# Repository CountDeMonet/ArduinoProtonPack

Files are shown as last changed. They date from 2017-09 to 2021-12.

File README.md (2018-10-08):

# Arduino Based Ghostbusters Proton Pack
Arduino Code for a Ghostbusters Neutrino Wand and Proton Pack

I'm in the process of building a proton pack for my son and this is the progress I have made so far. I have included the models for 3d printing, all sounds but the ghostbusters theme song, and the arduino code to control all of this. The models for 3d printing are scaled to 83%. The proton pack models are also mirrored for a left handed users pack. Once I have some time I'll post non-mirrored files. 

The models are based off the following things on thingiverse: 
* Main base model for the pack: https://www.thingiverse.com/thing:2479141
* Base model for the proton wand: https://www.thingiverse.com/thing:1128019
* Full scale proton wand the 83% one is based on: https://www.thingiverse.com/thing:2334883
* And a clippard valve with text: https://www.thingiverse.com/thing:2286284

This pack utilizes many off the shelf products for the electronics to make the build as easy as possible. Total cost is around $80 for the parts if sourced from amazon. You can find cheaper on ebay

* 1 arduino nano. You get 3 for $11.86: https://www.amazon.com/gp/product/B0713XK923
* 2 power converters to adjust the 11.1v lipo to 5v. You get 6 for $9.69: https://www.amazon.com/gp/product/B01MQGMOKI
* 1 Adafruit Audio FX Sound Board. It's the most expensive part at $23.80 but is awesome to work with: https://www.amazon.com/gp/product/B00Q3U42DM
* Audio amp $6.01 each: https://www.amazon.com/gp/product/B00PY2YSI4
* small speaker for my 83% scale build. You get 2 for $8.05. https://www.amazon.com/gp/product/B00NQ0LHNA
* 4 neopixel jewels for the cyclotron @ 5.49 each: https://www.amazon.com/gp/product/B0105VMT4S
* 1 neopixel jewels for the end of the wand @ 5.49 each: https://www.amazon.com/gp/product/B0105VMT4S
* two 8 neopixel light stick for the powercell @9.99 each: https://www.amazon.com/Adafruit-NeoPixel-Arduino-Integrated-Drivers/dp/B00IEDH26K
* Individual neopixels for venting, wand lights, and for the cyclotron if doing the spirit version. 100 for $16: https://www.amazon.com/Kuman-WS2812B-Addressable-Arduino-littlergb/dp/B01M5BEO1C
* 4 toggle switches:https://www.amazon.com/gp/product/B00HGAKDIQ
* 1 button:  https://www.amazon.com/gp/product/B01IU898QA
* 11.1v lipo to power the whole thing: https://www.amazon.com/Gens-ace-Battery-2200mAh-Airplane/dp/B00WJN4LG0

I bought the light covers from digikey

https://www.digikey.com/product-detail/en/visual-communications-company-vcc/CLF_280_ATP/CLF_280_ATP-ND/4515437 - light near the clippard
https://www.digikey.com/product-detail/en/visual-communications-company-vcc/SMB_200_RTP/SMB_200_RTP-ND/4515614 - sloblo
https://www.digikey.com/product-detail/en/visual-communications-company-vcc/SML_190_CTP/SML_190_CTP-ND/4515623 - Vent light front
https://www.digikey.com/product-detail/en/visual-communications-company-vcc/CMC_321_YTP/CMC_321_YTP-ND/4515456 - Vent light rear (no led tied to this one)

For the optional bargraph we are using the SparkFun SX1509 expander board and some resitor networks/bargraphs from digikey. If you want to use the bargraph you need to move the code from the test file into the main file and overwrite the stub functions. Since I won't be using it in my son's pack I removed it from the main file 
https://learn.sparkfun.com/tutorials/sx1509-io-expander-breakout-hookup-guide

* https://www.digikey.com/product-detail/en/sparkfun-electronics/BOB-13601/1568-1186-ND/5673772
* https://www.digikey.com/product-detail/en/bourns-inc/4611X-101-331LF/4611X-101-331LF-ND/3787988
* https://www.digikey.com/product-detail/en/bourns-inc/4606X-101-331LF/4606X-1-331LF-ND/1088983
* https://www.digikey.com/product-detail/en/sunled/XGUYX10D/1497-1086-5-ND/4745985
* https://www.digikey.com/product-detail/en/sunled/XGUYX5D/1497-1087-5-ND/4745584

Here's a video of the whole shebang put together

IMAGE ALT TEXT (https://www.youtube.com/watch?v=shoYI2D1AxI "Ghostbusters Arduino Proton Pack Update")

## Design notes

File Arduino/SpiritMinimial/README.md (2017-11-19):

I had a bunch of extra components lying around so I decided I would use them to upgrade the lighting on my Spirit pack. I wanted the standard powercell and cyclotron animations while I walk around. I kept the flashing light in the powercell when firing the wand but removed them on the cyclotron.  The result can be seen here:

IMAGE ALT TEXT (https://www.youtube.com/watch?v=f6RJXqUei0Q "Spirit Halloween Ghostbusters Proton Pack Lighting Upgrade")

There are options in the code to use the video game cyclotron animation or just the regular light cycle. 
```
const bool useGameCyclotronEffect = true;     // set this to true to get the fading previous cyclotron light in the idle sequence
const bool useCyclotronFadeInEffect = true;   // Instead of the yellow alternate flashing on boot this fades the cyclotron in from off to red
```

You can also adjust the speed of the animations by updating these variables:
```
// ##############################
// bootup animation speeds
// ##############################
const int pwr_boot_interval = 30;       // How fast to do the powercell drop animation on bootup 
const int cyc_boot_interval = 400;      // If useCyclotronFadeInEffect is false this alternates the cycltron lights yellow 
const int cyc_boot_alt_interval = 100;  // How fast to fade in the cyclotron lights from black to red on bootup

// ##############################
// idle animation speeds
// ##############################
const int pwr_interval = 50;            // how fast the powercell cycles
const int cyc_interval = 750;           // how fast the cycltron cycles from one cell to the next
const int cyc_fade_interval = 1;        // if useGameCyclotronEffect is true this is how fast to fade the previous cyclotron to light to nothing
```

Example components used for this update

* [Optional power converter set to 5V output: 6 for $9.69](https://www.amazon.com/gp/product/B01MQGMOKI)
* [Arduino Nano: 3 for $11.86](https://www.amazon.com/gp/product/B0713XK923)
* [Two Neopixel Sticks: 1 for $7.99](https://www.amazon.com/ACROBOTIC-8-Pixel-Addressable-NeoPixels-WS2812B/dp/B06XRPLCV1)
* [Individual Neopixel: 100 for $15.88](https://www.amazon.com/gp/product/B01AG8X1X8)

You can probably find these components cheaper if you look around. For instance I have found packages of the sticks for under $10 for 5 of them before

Here is a fritzing diagram of the whole setup with the power converter:

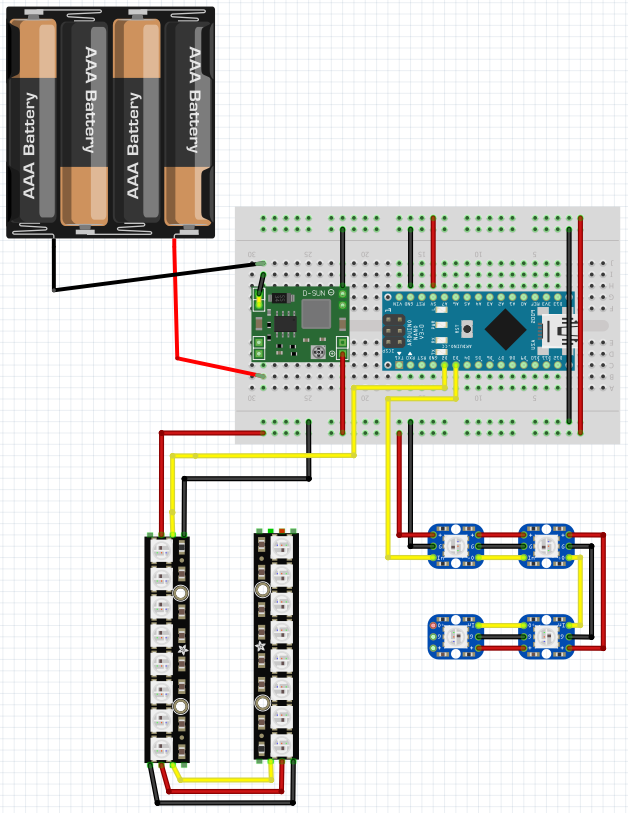
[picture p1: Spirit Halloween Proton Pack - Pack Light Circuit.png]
[

If you wanted to not use the power converter and are ok with the lights being a bit dimmer you can use this setup which would be simpler to solder up. The code would be the same
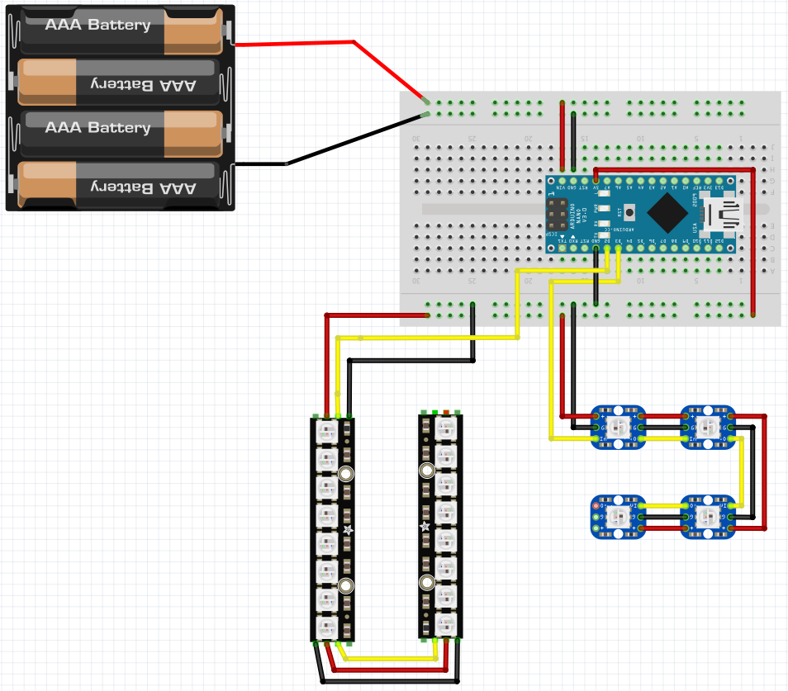
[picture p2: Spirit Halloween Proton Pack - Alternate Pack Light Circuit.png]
[

For my pack I'll be using an old 11.1v 1800mah lipo I had laying around. You could easily use 4 AAA's as well for this setup and they would last a long time. Something like this: https://www.amazon.com/Sackorange-Battery-Spring-Plastic-Holder/dp/B071ZQ3DGT would work well if you wanted to use that.

I like to use the power converter set to 5v output as the neopixels like more stable voltage than the 5v out on the arduino can handle. It allows you to go brighter with the neopixels. You could simplify this even more and remove the converter and use the arduino vin to take in the battery. I also like to use connectors but this whole setup could be easily soldered all together since it only uses 2 pins on the arduino. 

I also used some red and blue transparent folders to upgrade the light windows. Here are some pictures of the board I made and the installation. I created 2 models for 3d printing to make the installation easier. Those are also included in the github repo 

https://github.com/CountDeMonet/ArduinoProtonPack/tree/master/Model/SpiritHalloweenProtonPackMods

I installed everything with hot glue. Easy and effective. I'll probably add a switch to turn the lights on and off instead of plugging the battery in each time but the install only took a few minutes. 

[IMAGE ALT TEXT

[IMAGE ALT TEXT

[IMAGE ALT TEXT

[IMAGE ALT TEXT

[IMAGE ALT TEXT

[IMAGE ALT TEXT

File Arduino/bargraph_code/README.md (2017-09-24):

All of this assumes you are using a 15 led bar graph. I'm combining a 5 led and a 10 led bargraph from Digikey.

From the bargraph_code.ino you need to do the following:

What this chunk does is include the sx1509 libraries and sets up the configuration. This assumes the library is configured stock and the address has not been changed. It also defines the LED locations for the bar graph. Take this code and insert it into the header of the Neutrino_Wand.ino file

```c++
#include <Wire.h> // Include the I2C library (required)
#include <SparkFunSX1509.h> // Include SX1509 library

// SX1509 I2C address (set by ADDR1 and ADDR0 (00 by default):
const byte SX1509_ADDRESS = 0x3E;  // SX1509 I2C address
SX1509 io; // Create an SX1509 object to be used throughout

// bargraph helper variables
int seq_1_current = 0;  // current led in sequence 1
const int num_led = 15; // total number of leds in bar graph

// SX1509 pin definitions for the leds on the graph:
const byte SX1509_BAR_01 = 0;
const byte SX1509_BAR_02 = 1;
const byte SX1509_BAR_03 = 2;
const byte SX1509_BAR_04 = 3;
const byte SX1509_BAR_05 = 4;
const byte SX1509_BAR_06 = 5;
const byte SX1509_BAR_07 = 6;
const byte SX1509_BAR_08 = 7;
const byte SX1509_BAR_09 = 8;
const byte SX1509_BAR_10 = 9;
const byte SX1509_BAR_11 = 10;
const byte SX1509_BAR_12 = 11;
const byte SX1509_BAR_13 = 12;
const byte SX1509_BAR_14 = 13;
const byte SX1509_BAR_15 = 14;
```

The next chunk is added to the setup() function. This initialized the sx1509 board and makes sure the arduino is communicating. It configures the pin modes for the LED's as inputs and shutdown all of the LED's so they are not lit

```c++
  // Call io.begin(<address>) to initialize the SX1509. If it
  // successfully communicates, it'll return 1.
  if (!io.begin(SX1509_ADDRESS)) {
    while (1) ; // If we fail to communicate, loop forever for now but it would be nice to warn the user somehow
  }
  
  // configuration for the bargraph LED's
  io.pinMode(SX1509_BAR_01, OUTPUT);
  io.pinMode(SX1509_BAR_02, OUTPUT);
  io.pinMode(SX1509_BAR_03, OUTPUT);
  io.pinMode(SX1509_BAR_04, OUTPUT);
  io.pinMode(SX1509_BAR_05, OUTPUT);
  io.pinMode(SX1509_BAR_06, OUTPUT);
  io.pinMode(SX1509_BAR_07, OUTPUT);
  io.pinMode(SX1509_BAR_08, OUTPUT);
  io.pinMode(SX1509_BAR_09, OUTPUT);
  io.pinMode(SX1509_BAR_10, OUTPUT);
  io.pinMode(SX1509_BAR_11, OUTPUT);
  io.pinMode(SX1509_BAR_12, OUTPUT);
  io.pinMode(SX1509_BAR_13, OUTPUT);
  io.pinMode(SX1509_BAR_14, OUTPUT);
  io.pinMode(SX1509_BAR_15, OUTPUT);

  // set everything off initially
  shutdown_leds();
```

Right above the Loop() function in neutrino_wand.ino there are a number of intervals defined. The interval for the bargraph is already defined in neutrino_wand.ino. What this does is defines how often the bar graph is updated. If you wanted to speed up the bargraph this is the variable you would adjust. We define it here because in the main loop() we update this parameter so the bargraph can go faster when firing 

```c++
long firing_interval = 40;    // interval at which to cycle firing lights on the bargraph. We update this in the loop to speed up the animation so must be declared here (milliseconds).
```

The last part is to replace the stub functions in neutrino_wand.ino. At the very bottom of the neutrino_wand.ino file you will see these stubs

```c++
/*************** Bar Graph Animations *********************/
void shutdown_leds() {
  // stubb function for when I re-enable to bargraph
}
void barGraphSequenceOne(int currentMillis) {
  // stubb function for when I re-enable to bargraph
}
void barGraphSequenceTwo(int currentMillis) {
  // stubb function for when I re-enable to bargraph
}
```

I kept the code that calls the bargraph in the file so all you have to do is update these stubs with the actual code.  Simply copy this code and replace the stubbs with this.

```c++
/*************** Bar Graph Animations *********************/
// This is the idle sequence
unsigned long prevBarMillis_on = 0;   // bargraph on tracker
const int pwrcl_interval = 60;     // interval at which to cycle lights (milliseconds).
bool reverseSequenceOne = false;

void barGraphSequenceOne(int currentMillis) {
  // normal sync animation on the bar graph
  if (currentMillis - prevBarMillis_on > pwrcl_interval) {
    // save the last time you blinked the LED
    prevBarMillis_on = currentMillis;

    if ( reverseSequenceOne == false ) {
      switch_graph_led(seq_1_current, HIGH);
      seq_1_current++;
      if ( seq_1_current > num_led ) {
        reverseSequenceOne = true;
      }
    } else {
      switch_graph_led(seq_1_current, LOW);
      seq_1_current--;
      if ( seq_1_current < 0  ) {
        reverseSequenceOne = false;
      }
    }
  }
}

// This is the firing sequence
unsigned long prevBarMillis_fire = 0; // bargraph firing tracker
int fireSequenceNum = 1;

void barGraphSequenceTwo(int currentMillis) {
  if (currentMillis - prevBarMillis_fire > firing_interval) {
    // save the last time you blinked the LED
    prevBarMillis_fire = currentMillis;

    switch (fireSequenceNum) {
      case 1:
        switch_graph_led(2, LOW);
        switch_graph_led(14, LOW);
        switch_graph_led(1, HIGH);
        switch_graph_led(15, HIGH);
        fireSequenceNum++;
        break;
      case 2:
        switch_graph_led(1, LOW);
        switch_graph_led(15, LOW);
        switch_graph_led(2, HIGH);
        switch_graph_led(14, HIGH);
        fireSequenceNum++;
        break;
      case 3:
        switch_graph_led(2, LOW);
        switch_graph_led(14, LOW);
        switch_graph_led(3, HIGH);
        switch_graph_led(13, HIGH);
        fireSequenceNum++;
        break;
      case 4:
        switch_graph_led(3, LOW);
        switch_graph_led(13, LOW);
        switch_graph_led(4, HIGH);
        switch_graph_led(12, HIGH);
        fireSequenceNum++;
        break;
      case 5:
        switch_graph_led(4, LOW);
        switch_graph_led(12, LOW);
        switch_graph_led(5, HIGH);
        switch_graph_led(11, HIGH);
        fireSequenceNum++;
        break;
      case 6:
        switch_graph_led(5, LOW);
        switch_graph_led(11, LOW);
        switch_graph_led(6, HIGH);
        switch_graph_led(10, HIGH);
        fireSequenceNum++;
        break;
      case 7:
        switch_graph_led(6, LOW);
        switch_graph_led(10, LOW);
        switch_graph_led(7, HIGH);
        switch_graph_led(9, HIGH);
        fireSequenceNum++;
        break;
      case 8:
        switch_graph_led(7, LOW);
        switch_graph_led(9, LOW);
        switch_graph_led(6, HIGH);
        switch_graph_led(10, HIGH);
        fireSequenceNum++;
        break;
      case 9:
        switch_graph_led(6, LOW);
        switch_graph_led(10, LOW);
        switch_graph_led(5, HIGH);
        switch_graph_led(11, HIGH);
        fireSequenceNum++;
        break;
      case 10:
        switch_graph_led(5, LOW);
        switch_graph_led(11, LOW);
        switch_graph_led(4, HIGH);
        switch_graph_led(12, HIGH);
        fireSequenceNum++;
        break;
      case 11:
        switch_graph_led(4, LOW);
        switch_graph_led(12, LOW);
        switch_graph_led(3, HIGH);
        switch_graph_led(13, HIGH);
        fireSequenceNum++;
        break;
      case 12:
        switch_graph_led(3, LOW);
        switch_graph_led(13, LOW);
        switch_graph_led(2, HIGH);
        switch_graph_led(14, HIGH);
        fireSequenceNum = 1;
        break;
    }
  }
}

/************************* Shutdown and helper functions ****************************/
void shutdown_leds() {
  // reset the sequence
  seq_1_current = 1;
  fireSequenceNum = 1;

  // shut all led's off
  for (int i = 1; i <= 15; i++) {
    switch_graph_led(i, LOW);
  }
}

void switch_graph_led(int num, int state) {
  switch (num) {
    case 1:
      io.digitalWrite(SX1509_BAR_01, state);
      break;
    case 2:
      io.digitalWrite(SX1509_BAR_02, state);
      break;
    case 3:
      io.digitalWrite(SX1509_BAR_03, state);
      break;
    case 4:
      io.digitalWrite(SX1509_BAR_04, state);
      break;
    case 5:
      io.digitalWrite(SX1509_BAR_05, state);
      break;
    case 6:
      io.digitalWrite(SX1509_BAR_06, state);
      break;
    case 7:
      io.digitalWrite(SX1509_BAR_07, state);
      break;
    case 8:
      io.digitalWrite(SX1509_BAR_08, state);
      break;
    case 9:
      io.digitalWrite(SX1509_BAR_09, state);
      break;
    case 10:
      io.digitalWrite(SX1509_BAR_10, state);
      break;
    case 11:
      io.digitalWrite(SX1509_BAR_11, state);
      break;
    case 12:
      io.digitalWrite(SX1509_BAR_12, state);
      break;
    case 13:
      io.digitalWrite(SX1509_BAR_13, state);
      break;
    case 14:
      io.digitalWrite(SX1509_BAR_14, state);
      break;
    case 15:
      io.digitalWrite(SX1509_BAR_15, state);
      break;
  }
}
```

And with that everything should work. You'll have the idle animation on the bar graph and the firing animation with the speed increasing as you hold the button down as I showed in some of the videos.

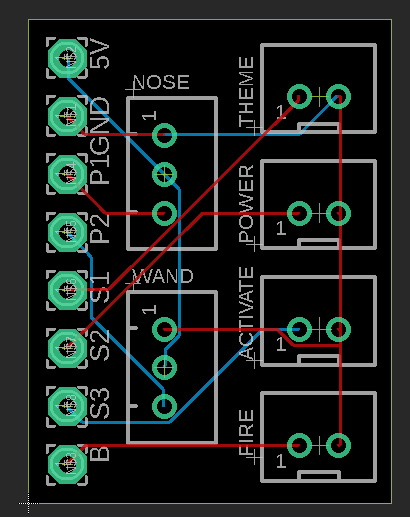
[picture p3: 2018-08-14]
eagle_wand_io_internal.png

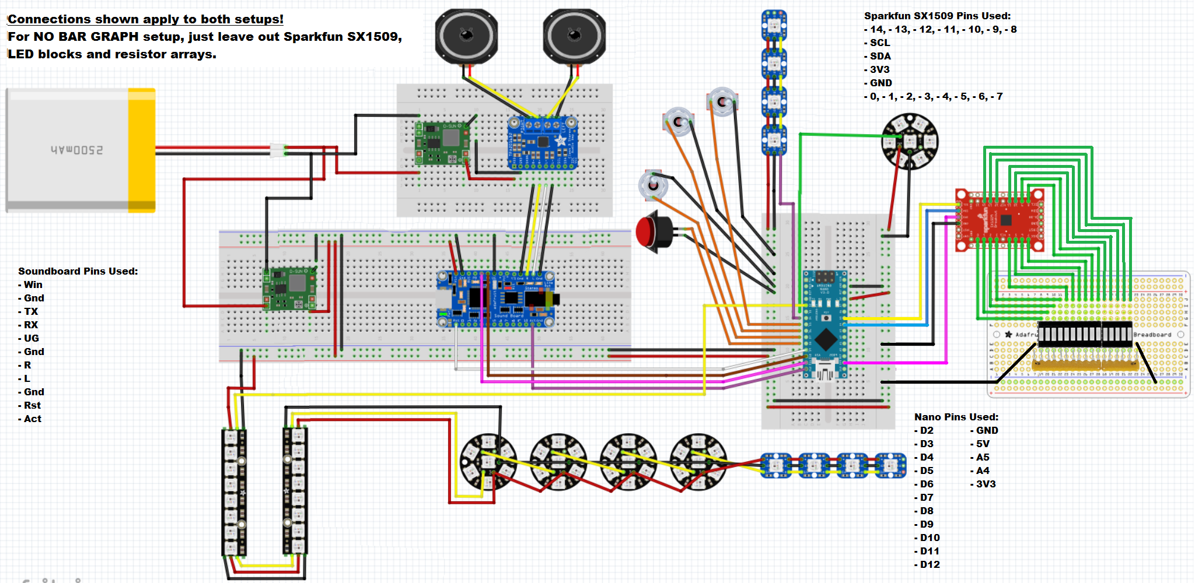
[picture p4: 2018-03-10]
Proton Pack Circuit Diagram - With Bargraph.png

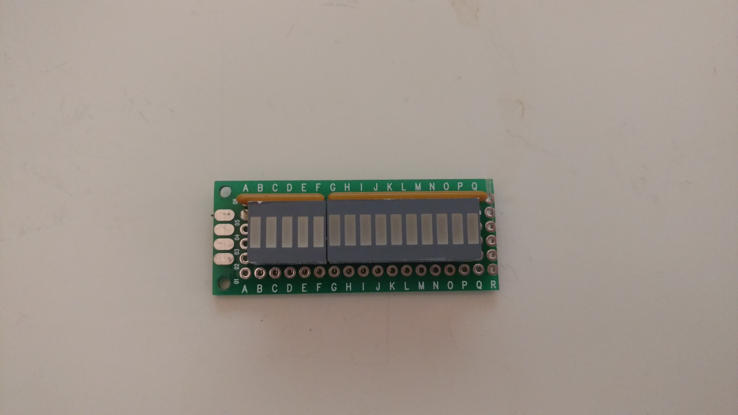
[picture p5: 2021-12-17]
bargraph_front.jpg

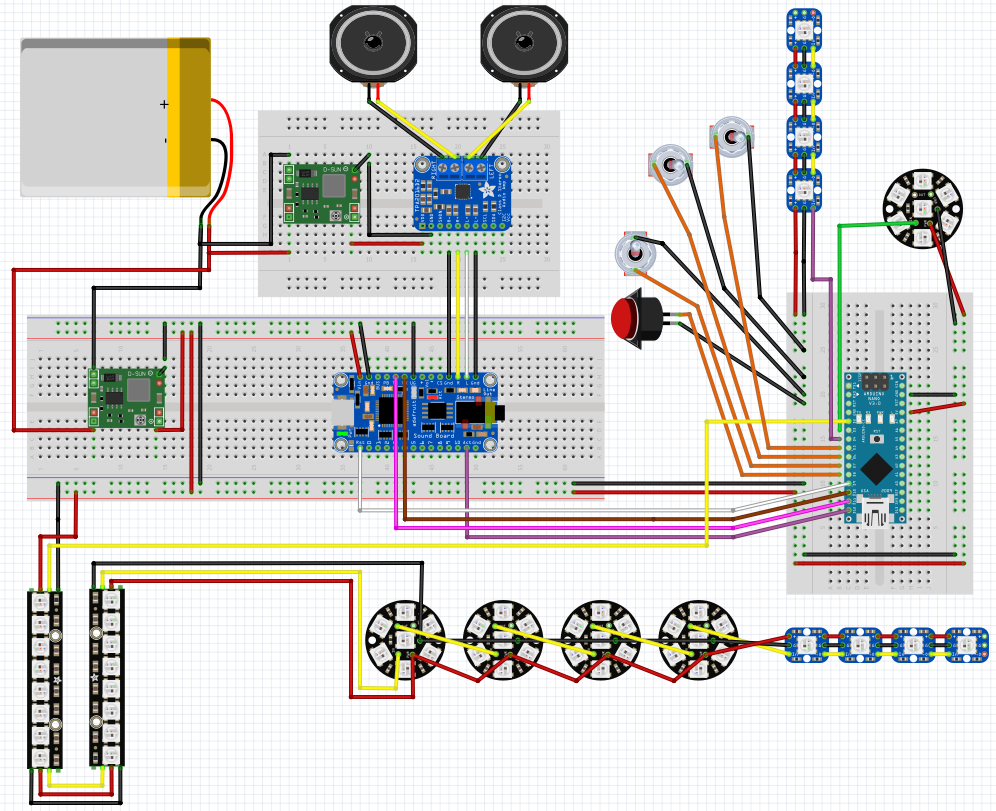
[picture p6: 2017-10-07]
Proton Pack Circuit Diagram - No Bargraph.png

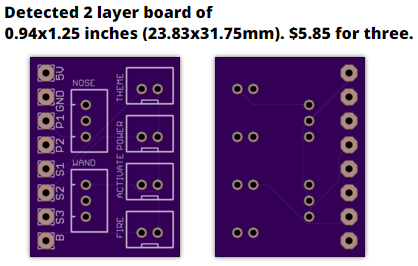
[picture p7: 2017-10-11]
eagle_wand_io.png

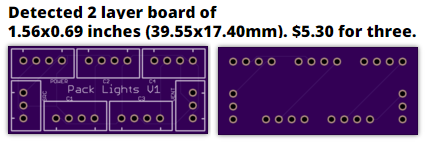
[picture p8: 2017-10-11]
eagle_proton_pack_neopixel_driver.png

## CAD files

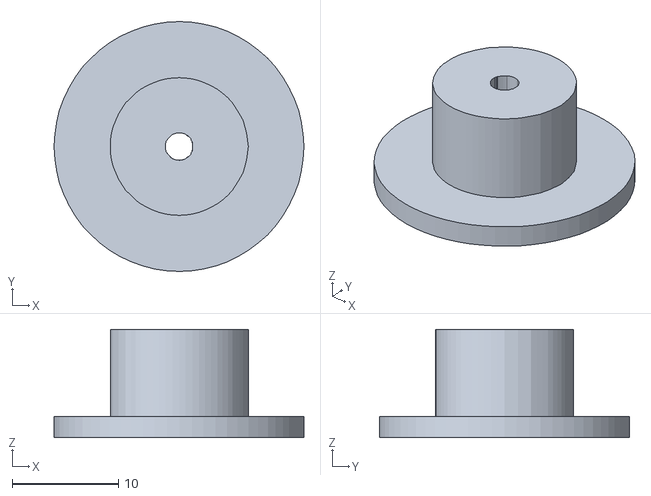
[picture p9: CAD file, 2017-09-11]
Model/83_Percent_Proton_Wand/gunbox_main_side_large_knob.stl
23.5 x 23.5 x 10.2

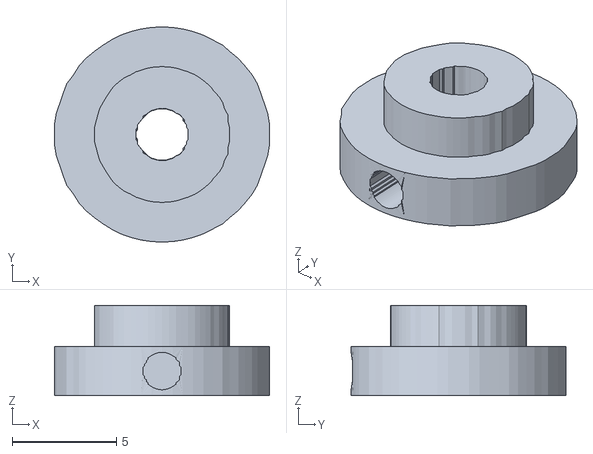
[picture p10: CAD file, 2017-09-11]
Model/83_Percent_Proton_Wand/gunbox_main_side_small_knob.stl
10.3 x 10.3 x 4.33

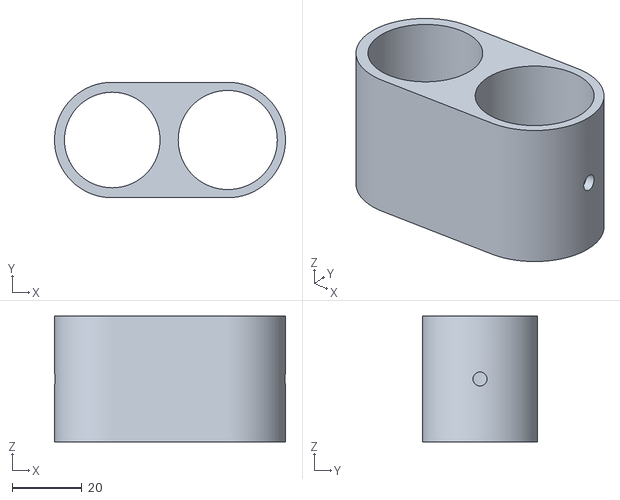
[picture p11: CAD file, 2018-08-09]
Model/83_Percent_Pack/back_brace_top.stl
66.0 x 33.0 x 36.0

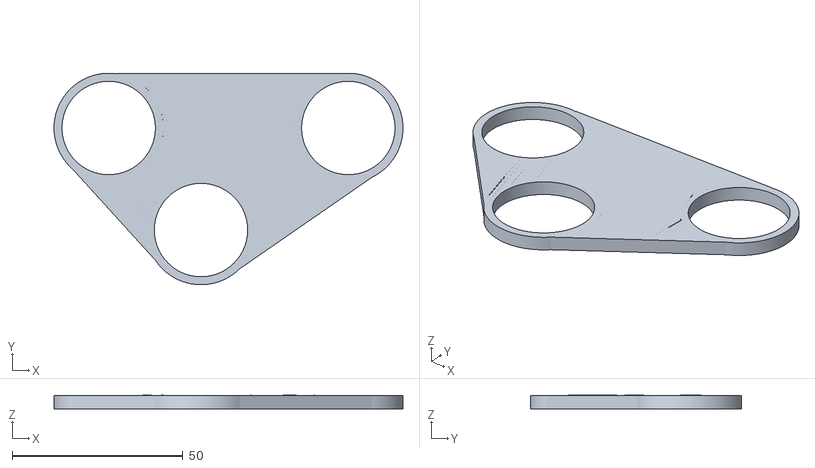
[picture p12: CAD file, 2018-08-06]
Model/83_Percent_Pack_Lefty/back_brace_standoff.stl
102.1 x 61.8 x 4.00

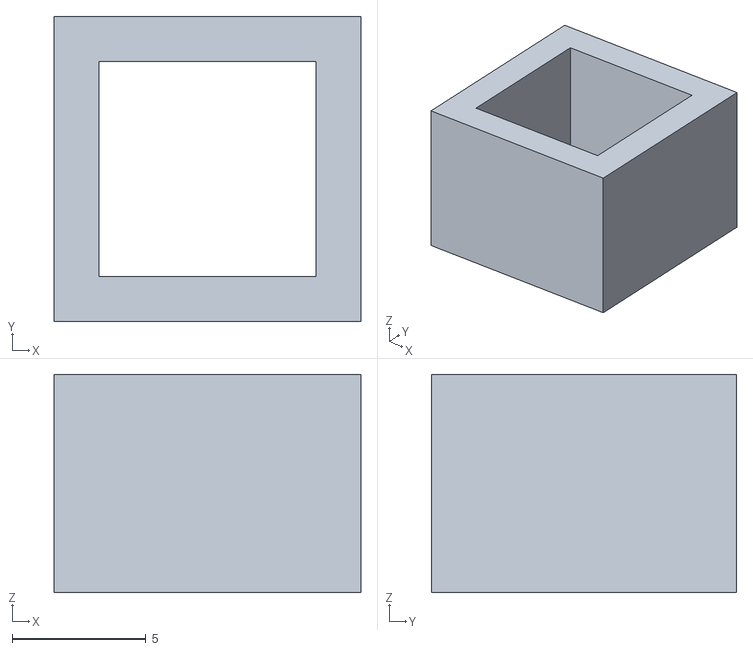
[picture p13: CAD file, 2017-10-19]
Model/83_Percent_Proton_Wand/gunbox_front_panel_side_connector.stl
11.5 x 11.4 x 8.16

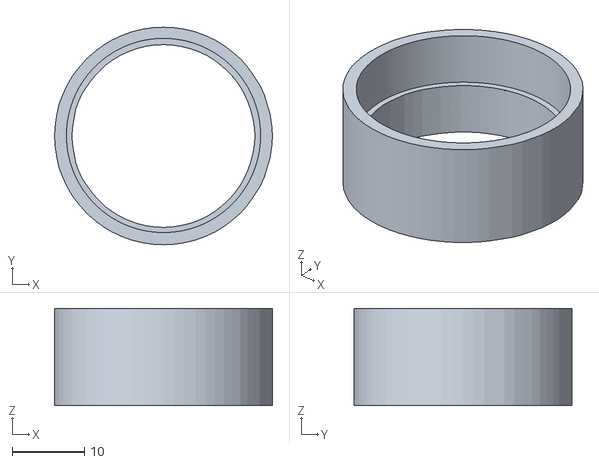
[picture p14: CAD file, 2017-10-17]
Model/SpiritHalloweenProtonPackMods/front_handle_clear_tube_adapter.stl
30.1 x 30.0 x 13.4

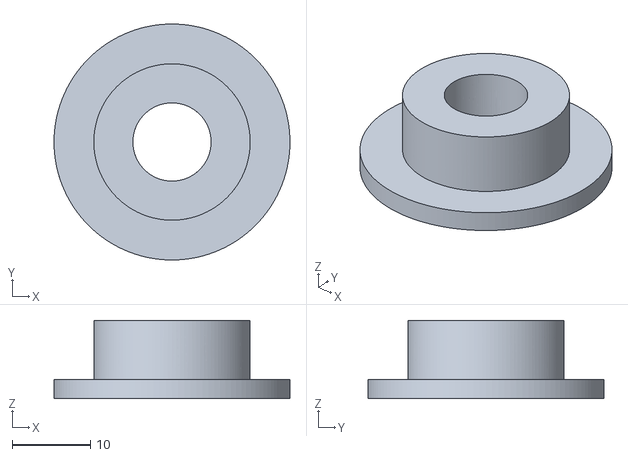
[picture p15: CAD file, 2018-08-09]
Model/83_Percent_Pack/back_brace_pvc_plug.stl
30.2 x 30.2 x 10.0

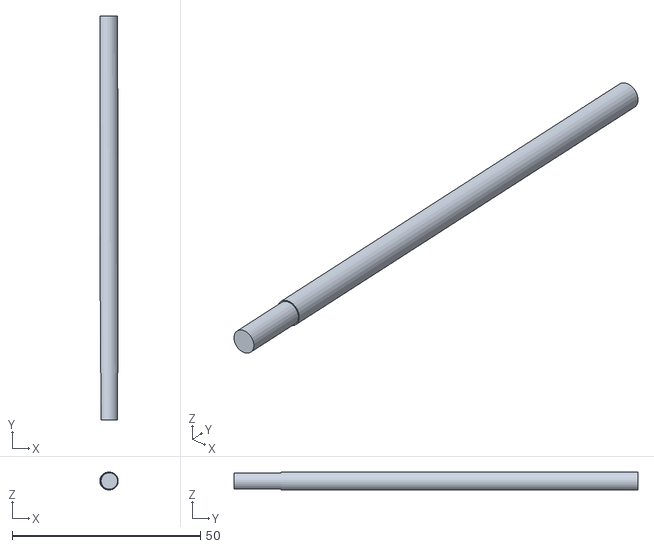
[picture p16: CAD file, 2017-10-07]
Model/83_Percent_Pack_Lefty/ion_rod_long.stl
4.89 x 107.3 x 4.74

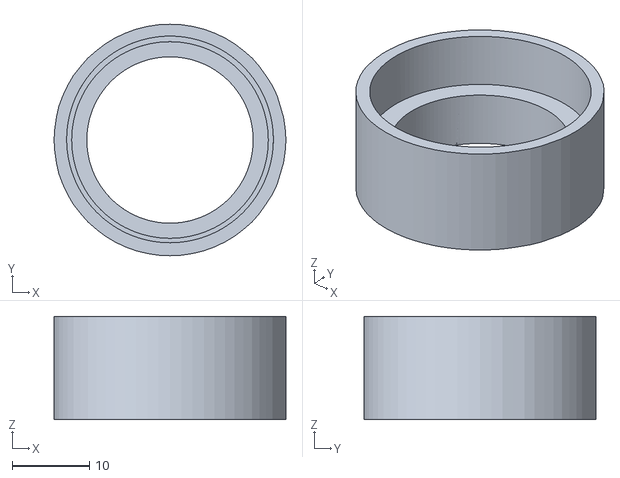
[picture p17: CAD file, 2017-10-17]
Model/83_Percent_Proton_Wand/front_handle_clear_tube_adapter.stl
30.1 x 30.0 x 13.4

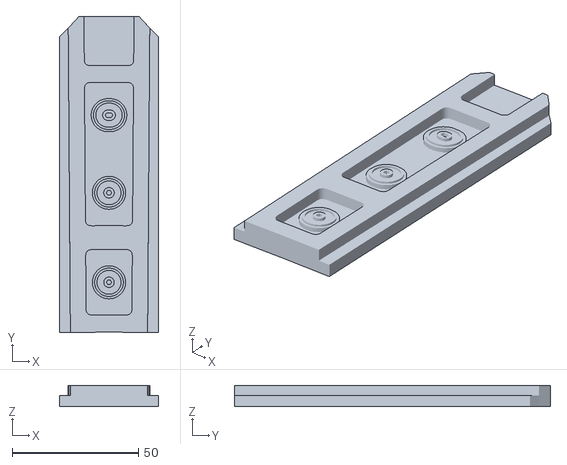
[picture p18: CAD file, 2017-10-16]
Model/SpiritHalloweenProtonPackMods/guntrack_spirit.stl
39.3 x 125.0 x 8.46

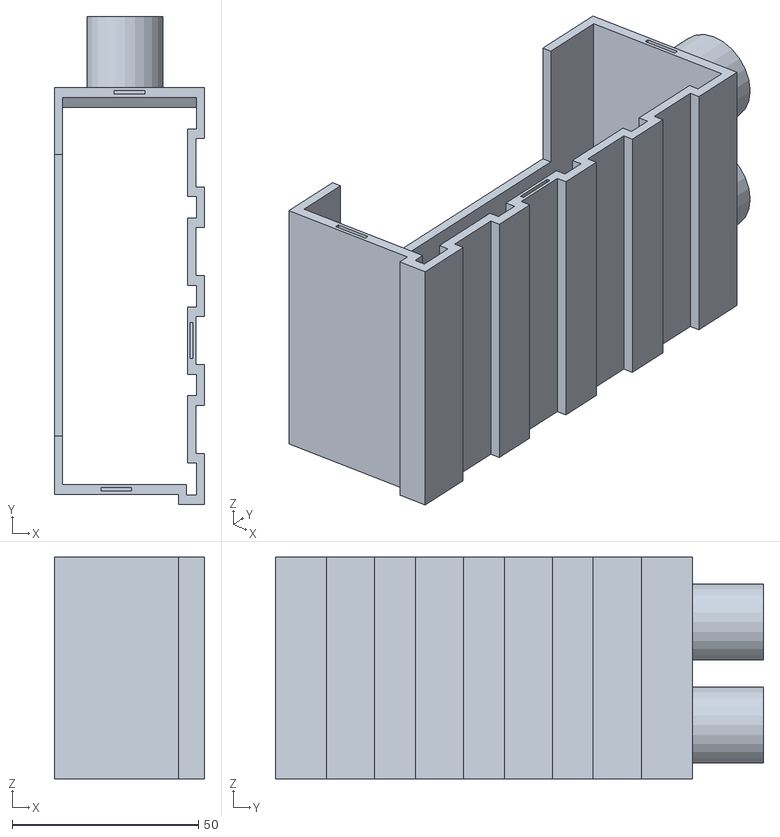
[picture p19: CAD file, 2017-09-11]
Model/83_Percent_Pack_Lefty/powercell_4.stl
40.3 x 130.9 x 59.4

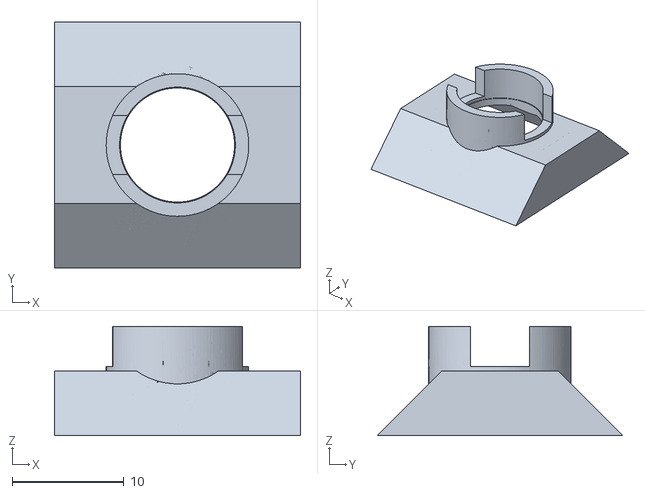
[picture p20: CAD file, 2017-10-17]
Model/83_Percent_Proton_Wand/gunbox_vent_light_mount.stl
22.0 x 22.0 x 9.76

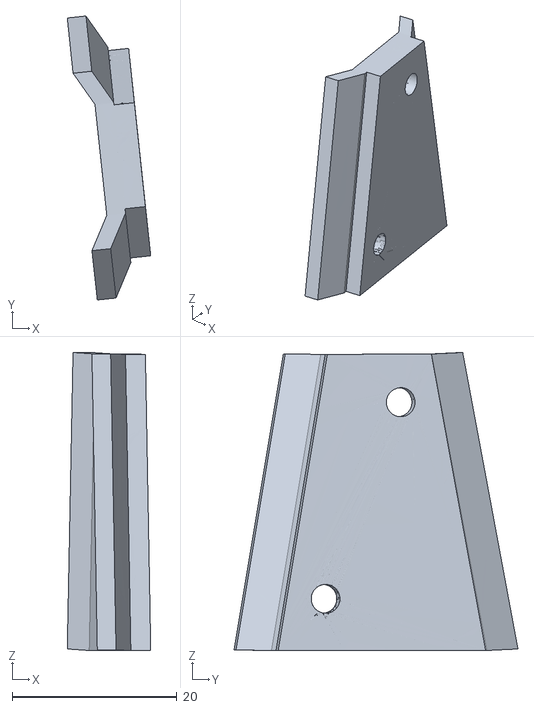
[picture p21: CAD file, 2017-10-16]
Model/SpiritHalloweenProtonPackMods/gunbracket_male.stl
10.1 x 34.5 x 36.2

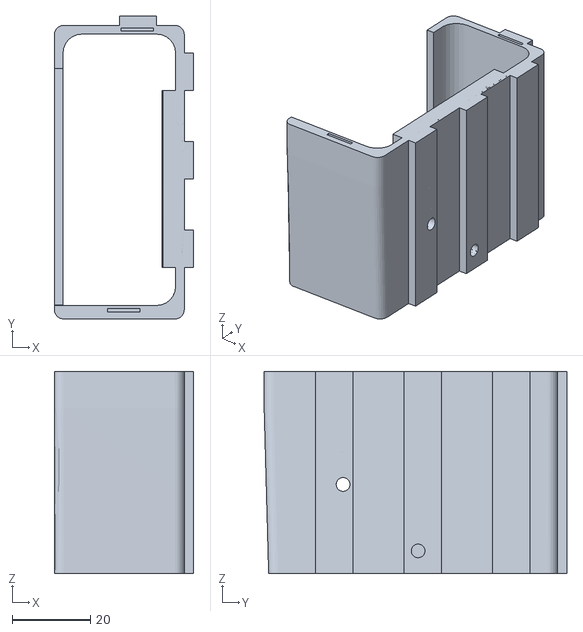
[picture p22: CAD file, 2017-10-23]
Model/83_Percent_Pack/gunmount_2.stl
35.6 x 77.3 x 51.6

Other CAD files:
Model/83_Percent_Pack_Lefty/ion_3.stl
Model/83_Percent_Proton_Wand/front_handle_end_piece.stl
Model/SpiritHalloweenProtonPackMods/gunbracket_base.stl
Model/83_Percent_Pack/base_1.stl
Model/83_Percent_Pack/base_2.stl
Model/83_Percent_Pack/base_3.stl
Model/83_Percent_Pack/booster_1.stl
Model/83_Percent_Pack/booster_2.stl
Model/83_Percent_Pack/booster_3.stl
Model/83_Percent_Pack/booster_4.stl
Model/83_Percent_Pack/booster_straight_barb.stl
Model/83_Percent_Pack/bumper_1.stl
Model/83_Percent_Pack/bumper_2.stl
Model/83_Percent_Pack/bumper_3.stl
Model/83_Percent_Pack/bumper_4.stl
Model/83_Percent_Pack/clippard_base.stl
Model/83_Percent_Pack/connectors.stl
Model/83_Percent_Pack/crankgen_1.stl
Model/83_Percent_Pack/crankgen_2.stl
Model/83_Percent_Pack/crankgen_3.stl
Model/83_Percent_Pack/cyclotron_1_closed.stl
Model/83_Percent_Pack/cyclotron_1_open.stl
Model/83_Percent_Pack/cyclotron_2.stl
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

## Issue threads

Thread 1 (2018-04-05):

Additional LEDs

SmilingJack85, 2018-04-05:
Hi there,
in the wiring diagram (without the bargraph), there are four LEDs after the jewels of the cyclotron, but i can´t find any information on what those are doing?
Also...is it possible to just use four single LEDs instead of the jewels for the cyclotron? I can´t figure out how i would have to change the code for that.

acfq48, 2018-04-05:
Those are the vent lights.  They turn bright white when the fire button is
released after overheating.  The answer to your second question is no.  The
jewels are individually addressed in order.  If you replace the four jewel
lights with four separate neopixels, they will all turn on at the same time
and the turn off for about 3 seconds.  The reason for this is that the code
references the lights in a string.  I'm not looking at the code but for
example, 1-7 light first, then 8-14, the 15-21, and lastly 22-28.  Then the
cycle repeats itself.  You would have to rewrite the code.  Check out my
version of this code on YouTube.  Af33 is the username.  The code is also
on github.  I just blew a 12v lithium battery so I think I'll do a wiring
video in a few weeks when I replace it.  Upload yours when youre done.
Keep the community rolling!

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

SmilingJack85, 2018-04-05:
Thanks for the super fast reply!
Of course, i forgot the vent lights...that makes sense.
That was the answer i expected, but i hoped for something else :-)
So i guess i have to order some more jewels (why do they have to be so expensive).
Or i figure something out to use some 2812 LEDs from a strip.
I´ll keep you updated, when i got it working.

grogking, 2018-04-05:
Im working on fixing the code to use single neopixels. Ill let you know when i get it working

Raktageno, 2018-04-05:
Do you have a diagram of the entire rig wired up with the custom boards? I've hit a wall, but I'm not sure if it's a failure to get the code to properly load or not.

SmilingJack85, 2018-04-05:
For the electronics part i spend about 200 (euro) when i order four more jeweils.
The pack will be build in a budget for now...maybe i'll upgrade later.
I don't worry about the hardware part, got some experience with electronics, but i don't know mich about the coding stuff.

acfq48, 2018-04-05:
Unfortunately I don't have a diagram.

Here's the link to my completed pack based heavily on count demonets code.
It runs off of an arduino mega with an LCD screen.  The code is in the
comments.

I've also bought the following on amazon for easy soldering:

Gikfun Prototype Shield DIY KIT For Arduino UNO R3 Mega 328P (Pack of 3
Sets) Ek1038x3

Adafruit Perma-Proto Half-sized Breadboard PCB - 3 Pack! [ADA571

Stereo 20W Class D Audio Amplifier - MAX9744
You need 12v to get the power up for this amp, but damn it's worth it!

Good luck!!!

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

CountDeMonet, 2018-04-27:
Hey sorry I just saw this. The spirit proton pack version of this code uses single neopixels for the cyclotron lights.

https://github.com/CountDeMonet/ArduinoProtonPack/blob/master/Arduino/SpiritMinimial/SpiritMinimial.ino

It shows how I do single neopixels. Basically the entire chain from the first powercell to the last vent light is indexed. I'll admit I didn't do it the same way for all of them so that is confusing. In this spirit pack code I just defined the start and end addresses for the individual lights like this

`
int c1Start = 0;
int c1End = 0;
int c2Start = 1;
int c2End = 1;
int c3Start = 2;
int c3End = 2;
int c4Start = 3;
int c4End = 3;
`

In this code example I moved the cyclotron leds to another pin to make it easier to understand. but the code is similar.

In the pull code, to fix it so that it's using 2 neopixel sticks (16 neopixels) for the powercell, individual neopixels for the cyclotron, and individual for the venting you would just change the definitions like this

Note that because we are using the neopixels sticks there will always be 16 of them in the chain. in this case I'm starting at the second light and illuminating 2-15 for the sequence. This allows you to adjust the animation so that it fits inside of the available powercell window and not use leds outside the window.

`
const int powercellLedCount = 14;                                        // total number of led's in the animation
const int powercellIndexOffset = 1;                                       // first led offset into the led chain for the animation

// now from 16 on we'll specify the individual cyclotron lights
const int c1Start = 16;
const int c1End = 16;
const int c2Start = 17;
const int c2End = 17;
const int c3Start = 18;
const int c3End = 18;
const int c4Start = 19;
const int c4End = 19;
const int ventStart = 20;
const int ventEnd = 23;
`

xblix, 2019-12-26:
in the other way  like adding a led
i wanna add 1 button in this code
this button is for fire_button2 for tips of wand. all work well. but i wanna a use this button2 for switching between 8 mode too.
i wanna
if safety_switch == 0  && fire_button2 == 1
switch mode ++1

each mode maybe is in a switch case and represent change for sounds and lights color
animation/speed can stay the same for all mode

‐-----

I try different way for implemented a button2 who's switch mode wjen safety_switch == 0.
but no succes

entire code in the loop section need to be replicate in sort of "main' switch case and where void animated lights function be replicated with minor change for color example : slime mode = cyclotron green light color & noseJewel  green light color

what could be the best way to implement this switch mode function and button2 without changing all the original code?  thanks if you could help a bit

xblix, 2020-01-14:
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

Done by StateMachine.
I add fire_button2
i add quick venting fuction
i add mode switch (13 different mode)

All by stateMachine function.

Thanks

grogking, 2020-01-14:
I was able to do this, but I had to make several changes in the code. I basically used the tip button to change the wand firing sounds and colors, as well as the colors of the cyclotron lights. Is that what you are trying to do?

xblix, 2020-01-14:
Yes and i do it is done!

I add a tip button for button_fire2
i could use this new button for a second firing sequence (example streamblast fire_button and  bosondart fire_button2. Perhap both could firing in the same times cause i use wav trigger board instead sfx.

Closed 2018-04-05.

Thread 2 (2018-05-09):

Can´t get the soundboard working

SmilingJack85, 2018-05-09:
Hi again,

@CountDeMonet
Sorry for opening another issue...and of course, thanks for your help!
I started building the full thing, with all the jewels :)

But right now i´m pretty desperate.
I can´t get the arduino to communicate with the soundboard i think.
With help i got the light working when changing the code so it works without the soundboard.
Also the soundboard itself works fine when testing, but i can´t get them to work together and i have no idea why.
I´m sure everything is wired correctly.
I´m using the FX Soundboard mini (https://www.adafruit.com/product/2341), but that shouldn´t make any difference right?

Would really appreciate any kind of tipp or advice.

acfq48, 2018-05-09:
Can you send a few pictures of your wiring?

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

SmilingJack85, 2018-05-10:
@acfq48 ...man you're fast, thanks!
Gonna try later, took everything apart again and have to sleep a bit, its 4am Here :-D

SmilingJack85, 2018-05-10:
https://photos.app.goo.gl/Fi0BcPEoPq1TCgO83

Hope you can See something on the pics. I know its a Messer, but its Just for Testing.

What i'm wondering about is the 5V of the arduino...isn't it supposed to power it via VIN instead of giving 5V out to the breadboard, which is already powered?

acfq48, 2018-05-10:
Its possible that the board isn't getting enough power.  Here's a snippet I
found from the internet.

I believe I can supply the Arduino with power in three different ways:

   - Use USB. The design trusts the 5V to be regulated, and does not
   regulate it in any way.
   - Use a regulated power source, trusted to be 5V, and connect it to GND
   and 5V.
   - Connect an unregulated power source, eg a battery, to GND and VIN.
   This should be above 6.2V (since the dropout voltage is 1.2V) and
   preferably between 9V and 12V. There is a built-in regulator that will
   supply the Arduino with exactly 5V.

When I built mine, I used an arduino mega so your results may differ.  But
if I had a problem with the board, the best idea is to take the separate
parts and test them one by one to troubleshoot for the problem.  You might
be able to do what I did and hook up a usb connector to the arduino and
plug it into a laptop or small 5v 1 or 2 amp power pack and see if the
light on the arduino board comes on.  If I remember correctly, I think I
might have slowly turned the power regulated chip up from like 4.5v to like
6 v and everything just sprung to life.  But don't do that unless your
willing to get new gear for whatever is connected to the board.  (I blew an
LCD screen doing that.)  https://youtu.be/Lqbb-O-3d8M

The beat initial suggestion that I have is to get all of your lights going
first.  If the lights aren't on and cycling with the button presses as they
should, you're shooting blind on the soundboard.  Of what I could see, your
wiring looked pretty good.

Best of luck and let us know how it's going!!!

On Thu, May 10, 2018, 6:30 AM SmilingJack85 <notifications@github.com>
wrote:

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

SmilingJack85, 2018-05-10:
ITS ALIVE!!!

I don´t know exactly what was wrong. I had some small issues, but nothing in particular why it didn´t work at all. Maybe it was just the combination of the little problems.
Anyway....its working now :-)
https://youtu.be/ziGLi3It3Ig

Thanks for your help!!!

@acfq48 Your pack is frikkin awesome! Would love to build something like that someday...if i had the time and the knowledge.

acfq48, 2018-05-10:
If you're looking to build my version, the code is here.  I use an arduino
mega but the set up is very similar.  I think you can even use an uno if
you wanted to.  They both just adds the pinouts for the LCD screen.

https://github.com/acfq48/Arduino-Proton-Pack-With-LCD-Screen

Keep us updated!

On Thu, May 10, 2018, 1:16 PM SmilingJack85 <notifications@github.com>
wrote:

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

CountDeMonet, 2018-05-17:
Hey sorry I missed this. For some reason I'm not getting emails from github and I don't check it every day. Glad you got it resolved and it's working. Looks great.

SmilingJack85, 2018-05-18:
@CountDeMonet
No problem, thanks anyways! Works like a charm yes... but  @acfq48 gave me another idea :-D

Maybe you guys can help me again (i already feel bad for bothering you with my "ignorance")
For the last hours i tried to combine your codes, to use more dialogue and music tracks.
The dialogues work, but i can´t get the music to work. It only plays the first track (Ray Parker Jr.).

Have to confess i don´t really understand the thing with the pointers, @acfq48 is using "const" and @CountDeMonet is using "char" for the tracks, and i guess somewhere here i just don´t get it.

Like i said before, i don´t know much about coding languages, so i would be really thankfull if you could help me with that...if i get the chance someday i would definately buy you guys a beer/coffee/lemonade :-)

CountDeMonet, 2018-05-18:
I figured out where I was missing a check and I'm now getting emails yay :) Not a problem asking questions. Happy to help.

The difference you are seeing in the code is just a memory optimization. There was a memory issue found when using the string constants to hold the track names. I'm guessing acfq48 pulled the code he based his on before the optimization. The strings were causing us to only be able to use so many tracks with the adafruit board. The solution to that issue was to switch to a char array which uses much less memory. On my new project I have over 50 tracks in use and will probably end up with over a hundred when I'm done and I'm not having any issues with memory.

The const part tells the compiler that this variable will never change and is a constant value. It's a compiler optimization for reduced memory usage.

acfq48, 2018-05-18:
Yeah...  what he said.  😀

I based my code off of demonets so listen to him.  Also, I used an arduino
mega so I guess I didn't care about memory optimization.  That and I'm a
noob who can barely write code so it's not very elegant.

Count, what kinda tricks are you working on over there?  Care to share with
the crew?

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

CountDeMonet, 2018-05-18:
Due to the fact that I've got so many tracks in the next project I'm not creating globals like I did for the proton pack. I have about 20 tracks that I really care about knowing so I reference those by name when I call the play function and the rest of it I reference by track number in a random way. It's an astromech droid like R2D2 so there are a lot of sounds that are random so the more the better. All of the code is posted here:

https://github.com/CountDeMonet/ArduinoAstromechDomeController

current status video.
https://www.youtube.com/watch?v=Q4jPT27Jjtw

I'm actually installing the speaker amp, audiofx board, and speakers tonight to get him talking :)

SmilingJack85, 2018-05-18:
This is the droid i´m looking for! Thats amazing!
What is the little guy made of? Looks a bit like you 3D printed the parts?

Thanks for the explanation!
Got it working now and can´t stop smiling :-D

CountDeMonet, 2018-05-18:
Glad you got it working. The mega has tons of memory compared to the nano or even uno so sometimes tricks are needed and it's not always clear why. They don't fail in clear ways.

The droid is mostly 3d printed with lots of hardware holding it together. Been working on it since late december. Hope to be doing the finishing work soon. Almost done finalizing the electronics and testing the drive train. It's pretty quick :)

SmilingJack85, 2018-05-18:
Its working, so better leave at it is now.
I don't know If i would have to change something If i'd switch to a mega, so thats no option for me :smile:
Maybe i'll try...got one laying around here.

Really great work!
Can't wait to see it finished.
(I told my wife we need a 3D printer, maybe that will finally convince her)

Thanks again for your help!
Now i can sleep in peace...its already 4am here again :joy:

CountDeMonet, 2018-05-18:
I was just mentioning the mega because it is a different platform than the other ones. It's a good option if you need a lot of inputs but if you're trying to keep things small and lightweight the Nano is my preferred.

I love my 3D printer. I printed a proton pack and now I'm almost done with it Astromech droid so there's a lot you can do with it. Plus my wife has me making all kinds of things for the house like mounts for this thing or that thing.

acfq48, 2018-05-18:
Yeah, I used the mega because I needed the sda and scl outputs for my LCD
screen.  That and the fact that I had no idea what I was doing and thought
that all arduino systems were interchangeable. Wrong...

It took me some time to fiddle with the code to get it to work on a mega.
Since it's all in the proton pack anyway I didn't much care for the space
savings.  I'm still trying to talk count into helping me put the GB the
video game sounds and neopixel color changes in i.e. slime mode etc. But
I'll have to be patient for this awesome droid to be completed.  😉

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

SmilingJack85, 2018-07-05:
Hi again!
I didn´t know where to post this, so i hope its ok to use this thread one more time :-)
We had to rush some things, to get everything done for the convention, but the packs did turn out pretty good:
https://youtu.be/xv4iKZd05xQ

CountDeMonet, 2018-07-05:
@SmilingJack85 Looks great! nice work.

Closed 2018-05-10.

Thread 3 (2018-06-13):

Vent light question

ryandcole, 2018-06-13:
This looks awesome.  What neopixels did you use for the venting lights on the pack and wand?

CountDeMonet, 2018-06-13:
Thanks. This is the set I bought. Have a few left over still :)

https://www.amazon.com/gp/product/B01AG8X1X8

ryandcole, 2018-06-13:
Awesome.  Thank you!  Starting to plan the build now with the Spirit pack and updated 3D printed wand.  Hope to have it ready for Halloween!  Thanks!

CountDeMonet, 2018-06-13:
Good luck. I really enjoyed this build. Happy to answer any questions that come up

ryandcole, 2018-06-13:
Awesome.  I'm sure that I'll have them!  Below are the goggles I made for last Halloween.
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

acfq48, 2018-06-13:
What wire did you use count?  It's triple stranded and nicely kept
together.  Mine kinda looks like a hodgepodge of 24 gauge garbage...

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

CountDeMonet, 2018-06-13:
I used a few different kinds. For the wires that are connected I used this ribbon wire

Uxcell a16030200ux0389 Ribbon IDC Cable Wire Rainbow Cable Flat Color Rainbow, 2 m, 6.6', 40 Way, 40 Pin https://www.amazon.com/dp/B01JRA853W/ref=cm_sw_r_cp_taa_i_v3AiBbWW0KRZ4

I also used it for the pack ribbon wire that is displayed on the outside.

I like this stuff for pretty much everything else. Very flexible and strong

Striveday&trade;Flexible Silicone Wire 24awg Electric wire 24 gauge Coper Hook Up Wire 300V Cables electronic stranded wire cable electrics DIY BOX-1 https://www.amazon.com/dp/B01LH1G2IE/ref=cm_sw_r_cp_taa_i_t6AiBbMJKFZTC

Closed 2018-06-13.

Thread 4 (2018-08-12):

Cant compile with bar graph

G1Soundwave, 2018-08-12:
Ive been fighting with this a bit now, the code without bar graph works great, but with bargraph, it stops compiling and gives this error- "'shutdown_leds' was not declared in this scope" I would try to fix it myself, but to be honest, I know almost nothing about coding. But I will say, even without the bargraph, excellent job on it!

CountDeMonet, 2018-08-12:
That is really odd. The code compiles for me. I would make sure you have pulled the latest code from the repository and retry compiling. That function it is complaining about is down at line 1102 and should look like this

`
void shutdown_leds() {
  // reset the sequence
  seq_1_current = 1;
  fireSequenceNum = 1;

  // shut all led's off
  for (int i = 1; i <= 15; i++) {
    switch_graph_led(i, LOW);
  }
}
`

acfq48, 2018-08-12:
For anyone interested:  Spirit Halloween is releasing a ghost trap and PKE
meter among a few other new Ghostbuster items.  They're running for $50 and
$35 respectively and look pretty good.  I'll be working on a foot pedal mod
for the trap as soon as I get it but if anyone beats me to it, be sure to
post.

https://www.spirithalloween.com/product/ghostbuster-ghost-trap-ghostbusters/164228.uts?keyword=ghost
trap&thumbnailIndex=1&Search=Find+It

Enjoy!

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

G1Soundwave, 2018-08-13:
Not sure what happened, but seems it was missing those sections in the code. Redownloaded it, and working fine. Dont know why I didnt think to try that. Thanks alot.

Closed 2018-08-13.

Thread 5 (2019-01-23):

No booting up

fstanley28, 2019-01-23:
I have everything loaded on the soundboard and nano both power up(lights turn on on both boards) but I get nothing when I flip switches. I believe I have everything wired correctly. Any help would be appreciated.

acfq48, 2019-01-23:
Post some pictures or a video and link to it.

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

CountDeMonet, 2019-01-23:
A while back I removed the stop if there are issues with the sound board. It is the most finicky part of the whole thing. It should be working assuming all connections are good. Check solder joints first and foremost. Pictures of the setup would help as well.

fstanley28, 2019-01-23:
I appreciate the super quick repsonses. I will get some video/photos up later tonight. Thank you!

fstanley28, 2019-01-24:
Here is the video link: https://youtu.be/wZFvqCkVhzI

Here is a link to a few photos:
https://drive.google.com/drive/folders/1hw2k3sZqJJ9PCTk1Jc0FeTagvnJx77Eg

My wiring is a bit of a mess. The last time I wired up anything up, I was 18 working at RadioShack.

fstanley28, 2019-01-24:
No they have never swtich on. I have not tried it with out the soundboard. I wll try with out the board momentarily.

CountDeMonet, 2019-01-24:
I'd recommend loading up the spirit pack version wish is really minimal and only does  the lights. In this version the powercell and cyclotron lights are split up so you can only get the powercell working but it ignores switches and the sound board and you can see if the powercell works at a minimum. It's good to see something work when you are starting in on these projects.

https://github.com/CountDeMonet/ArduinoProtonPack/blob/master/Arduino/SpiritMinimial/SpiritMinimial.ino

CountDeMonet, 2019-01-24:
I'm having an issue with google drive so I can't see the pics for some reason. Hope I'll be able to later. I watched the video and it is hard to make out how everything is hooked up. There are a lot of wires in this project :) Sometimes I find it's best to test components individually when there is a general problem like this. Maybe use some example switch and button sketches to test the input components.  I would definitely start with the switches since those are what control everything else.

If you have a multimeter verify the voltages at various places around the circuit.

fstanley28, 2019-01-24:
@countdemonet I’ll give the spirit code a try. I uploaded the pictures in another format. The first set was in some weird iPhone format.

fstanley28, 2019-01-25:
@countdemonet got it working with the spirit only.  https://youtu.be/We_NuNtLlww

On to more testing.

acfq48, 2019-01-25:
Great job!  That at least proves that your initial setup and arduino work.
Count, do you recall if the code works for all of the blue lights or does
it skip one?  I suspect that one of the neopixels on this rig is burnt out
and the stick needs to be replaced.

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

CountDeMonet, 2019-01-25:
Yeah that is interesting. The default code does have a limit built in to show 14 leds in the sequence (how many fit in the spirit window). It looks like it was updated to show all 16. It is LED #7 in the chain if you wanted to try and change the color directly.

this would try to make the LED bright red. Comment out the current loop and then place this in there. You could test all of the leds 1 by 1 in the chain with this.

`
void loop() {
  powerStick.setPixelColor(7, powerStick.Color(255, 0, 0));
  powerStick.show();
  delay(1);
}
`

So now that we know that the led's work for the most part the next bit to figure out is why is the full code not moving forward and running. Checking the switches is your next step.

fstanley28, 2019-01-26:
All lights are now working! No sound out of the sound board. Seems to not be triggering. Getting a small pop from the speakers when the battery is plugged in, good news there. Has anyone had defective Adafruit soundboards? I plugged it it and loaded it initially but now when I plug it into my comp it’s not recognized. Maybe it’s defective. I’m going to try a replacement m. Thanks for everyone’s help!

CountDeMonet, 2019-01-26:
There is a sketch installed with the adafruit libs that is great for testing the audio board. It let's you interactively control from the Arduino using serial monitor. I use this a lot to get everything setup on the fx board and make sure everything is working. Just update the PIN numbers in the example sxetch and upload it to Arduino.

https://learn.adafruit.com/adafruit-audio-fx-sound-board/serial-audio-control

fstanley28, 2019-02-08:
Just an update on progress. Got the sound working. Everything is firing as it should! Now to put everything together for the finished pack. I appreciate everyone’s help here.

acfq48, 2019-02-08:
Awesome news!  Post a vid when you're all wrapped up.

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

CountDeMonet, 2019-02-08:
Excellent! Yes please share a video I'd love to see it

Closed 2019-04-22.

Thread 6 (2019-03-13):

help

BSKStudio, 2019-03-13:
This is something probably that I'm doing wrong.  Im having a issue when Im importing the zip file into my library?  its not allowing the queue array to and other files to import?

CountDeMonet, 2019-03-13:
Make sure you install the libraries to the library folder for the ide

https://www.arduino.cc/en/guide/libraries#toc3

BSKStudio, 2019-03-15:
Awesome thank you!

Autocado, 2021-08-15:
how do I uploads the code and sound

CountDeMonet, 2021-08-15:
@Autocado you are going to want to review this page on getting started with the arduino

https://www.arduino.cc/en/main/howto

and this page on uploading files to the audiofx board

https://learn.adafruit.com/adafruit-audio-fx-sound-board/copying-audio-files

Closed 2019-04-22.

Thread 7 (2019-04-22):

Strange problem.

criticalkaos, 2019-04-22:
I have built all the circuit using a breadboard all worked fine, i bought a solderable breadboard and i am slowly moving everything over, all powers up but I am having a strange issue I have never come across when the board is laying flat the leds run slow when I put it on its side it speeds up to normal speed this also happens even if i wave my hand in front of the back of the board not touching it, I have re soldered entire new boards 3 times now changing the nano 3 times also swapping the led modules, and cables but it still does the same im totally lost.

i have not completely wired everything up yet nano is soldered cyclotron, power cell and vent lights all wired and the wand light is wired with one switch for testing am i missing something?

ever come across anything like this?

CountDeMonet, 2019-04-22:
Slowdown would indicate an issue with the FX board if that is what you are using. Could be a bad ground or weak solder joint on the tx/rx pins. Slowdown is almost always a communication problem with the audio board though. I'd use the adafruit test program to make sure it's working properly

https://learn.adafruit.com/adafruit-audio-fx-sound-board/serial-audio-control

Just update the pin numbers in the sketch to the ones used for the audio board and upload to the arduino. The test sketch is the example included with the library for the arduino.

criticalkaos, 2019-04-22:
Thanks for the quick response at this point I dont actually have the audio board connected that all seemed to work fine on the breadboard at this point all I have connected is the pack lights. I was originally thinking it might be bad soldering but I have done it 3 times now using new protobaords new nanos even purchased new solder and used different cables but I get same result. It could be bad ground or some sort of interference as it does speed up if I touch the pins on the board. Scratching me head on this one.

CountDeMonet, 2019-04-22:
Are you using the full code and don't have the soundboard attached you need to make a mod to the code to disable the soundboard.

Comment out

In the header

SoftwareSerial ss = SoftwareSerial(SFX_TX, SFX_RX);
Adafruit_Soundboard sfx = Adafruit_Soundboard( &ss, NULL, SFX_RST);

In setup()

// softwareserial at 9600 baud for the audio board
ss.begin(9600);

// set act modes for the fx board
pinMode(ACT, INPUT);

The entire contents of playAudio() and playDialogTrack() functions

and then in the main loop() change

int playing = digitalRead(ACT);

to

int playing = 0;

If you are not using the full code then are there any modifications you have made to the script?

criticalkaos, 2019-04-22:
Ooooh so my problem could just be the fact I dont have the sound board connected. I have been running the full code no changes made but I like to test things along the way, do a bit test it do some more test it again just using one neopixel strip connected if it runs then carry on I may not have noticed the speed difference up until now, I have been doing this in my spare time over the past couple of weeks so may of not noticed until now and just assumed it should work without the audio board connected.

CountDeMonet, 2019-04-22:
yeah the full code needs the audio board. I recently remove the RST code that would completely stop all initialization if the board was not found and to free up a pin. Try disabling the board and I expect things will speed up

criticalkaos, 2019-04-22:
Success it works fine now I have sound board connected I honestly thought it wouldn't make any difference but so far no issues. Thanks for the help it works a treat now.

CountDeMonet, 2019-04-22:
Great, glad things are working now

criticalkaos, 2019-10-24:
Hi sorry to be a pain just noticed you have updated the code to include ecig do you have any more info how to connect up the relay to the arduino I have have everything ready to go.

ericbanker, 2019-10-24:
The signal pin for the relay is 13. Then you also want to connect the ground for the relay to your common ground for the Arduino and other components. From that point on the Arduino side of the relay is done. If the relay is working backwards from how it should look in the code and there are a few places where you can reverse the relay function.

criticalkaos, 2019-10-24:
Nice one cheers mate I'll give it a try tonight.

Closed 2019-04-22.

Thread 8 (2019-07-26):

Battery options?

SmokeFountain, 2019-07-26:
Hello, I'm an absolute beginner at this and giving this a shot for my proton pack build. I have zero experience with lipo batteries and read a lot of stories of them being dangerous when not handled properly (Dangerous when overcharging or when they get under 3V) so I was wondering if there was an alternative for the lipo that I could use to power this project for a decent amount of time. Sorry if this is a really nooby question but I'm  pretty clueless and this is my first arduino project so I'm learning along the way.

acfq48, 2019-07-27:
Check out my video on this.  I had the same question years ago and as it
turns out, the 12v lipo can be replaced with 8AAs for similar results.  AA
batteries produce 1.5v so 8x1.5=12. When placed consecutively, one after
the other of course.  They sell holders like that on eBay and Amazon for
about 8 bucks or so.

My pack uses both Lipo and AA and honestly, it was probably overkill.  I
just wanted to be able to take it to a con and if my lipo ran out then I
could switch and keep the pack going forever.  Just be sure to put the
current through the buck converter to downsize the voltage to 5v.  If you
pour 12v straight into your electronics it will fry them.  Lots of smoke
and smoke is bad.  Get a cheap voltage reader and find a video on how to
use it.  Put the 12v into the converter and read the other end while
adjusting the small screw on the converter.  Once you hit 5v, then and only
then connect the arduino.  (I actually think the arduino may take up to 9v
but I'm not sure enough to advise that)  if you use the adafruit sound
board I think it should take the full 12v but check the pinout drawing to
be sure.  If so, you just tap a line off of the 8AA before it goes to the
buck converter and then onto the board.

Hope that helps!

On Fri, Jul 26, 2019, 4:32 PM SmokeFountain <notifications@github.com>
wrote:

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

ericbanker, 2019-07-27:
I've been using lipos for more than 15 years now and as long as you charge them with a good charger there won't be any issues. I have packs that I have over discharged and the good charger won't charge them.

That said there are many options for powering any device. I like lipos because of the weight to capacity.  I use 11.1v 2200 mAh packs for the proton pack and I can get a full day of usage out of it.

The voltage is the other part of this. Arduino likes 5v and most everything in this design used that voltage or lower. You could go with a two cell lipo at 2000mAh as well. I had many 3 cell from my rc days which is why I used that. As long as you are over 5v and a decent capacity you will be fine

Now on to the converter. The Arduino 5v out is very limited so I chose to power everything from the buck converter instead of the Arduino 5v out. You will run into issues due to the current draw if you tried to power all off the Arduino 5v or USB. The amp for audio also needs a very stable voltage for good sound. You can test it all off the Arduino usb as long as you keep the volume very low. For real world use power separate

Hope that helps a bit

SmokeFountain, 2019-07-27:
Awesome, thanks so much for the responses😊. I have the buck converters so I’ll definately use them. I have one of those 8AA battery holders lying around so I’ll use that for now and when everything is set up and working as it should I’ll give the Lipo a try for the sake of it being rechargeable. Thanks again😊👍🏻.

acfq48, 2019-07-27:
Best of luck buddy!  Post some vids of the finished product.  😁😁😁

On Sat, Jul 27, 2019, 1:07 AM SmokeFountain <notifications@github.com>
wrote:

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

Closed 2019-11-19.

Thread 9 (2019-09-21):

Code Issues

kbritton87, 2019-09-21:
Hi mate, hoping you can help me, getting all the libraries sorted but keep getting the below issue.

libraries\SparkFun_SX1509_Arduino_Library\SparkFunSX1509.cpp.o (symbol from plugin): In function `SX1509::SX1509()':

(.text+0x0): multiple definition of `REG_I_ON'

sketch\Arduino_Code.ino.cpp.o (symbol from plugin):(.text+0x0): first defined here

libraries\SparkFun_SX1509_Arduino_Library\SparkFunSX1509.cpp.o (symbol from plugin): In function `SX1509::SX1509()':

(.text+0x0): multiple definition of `REG_T_ON'

sketch\Arduino_Code.ino.cpp.o (symbol from plugin):(.text+0x0): first defined here

libraries\SparkFun_SX1509_Arduino_Library\SparkFunSX1509.cpp.o (symbol from plugin): In function `SX1509::SX1509()':

(.text+0x0): multiple definition of `REG_OFF'

sketch\Arduino_Code.ino.cpp.o (symbol from plugin):(.text+0x0): first defined here

libraries\SparkFun_SX1509_Arduino_Library\SparkFunSX1509.cpp.o (symbol from plugin): In function `SX1509::SX1509()':

(.text+0x0): multiple definition of `REG_T_RISE'

sketch\Arduino_Code.ino.cpp.o (symbol from plugin):(.text+0x0): first defined here

libraries\SparkFun_SX1509_Arduino_Library\SparkFunSX1509.cpp.o (symbol from plugin): In function `SX1509::SX1509()':

(.text+0x0): multiple definition of `REG_T_FALL'

sketch\Arduino_Code.ino.cpp.o (symbol from plugin):(.text+0x0): first defined here

collect2.exe: error: ld returned 1 exit status

Multiple libraries were found for "Wire.h"
 Used: C:\Program
Multiple libraries were found for "SparkFunSX1509.h"
 Used: C:\Users\KarlB\OneDrive\Documents\Arduino\libraries\SparkFun_SX1509_Arduino_Library
Multiple libraries were found for "QueueArray.h"
 Used: C:\Users\KarlB\OneDrive\Documents\Arduino\libraries\QueueArray
Multiple libraries were found for "Adafruit_Soundboard.h"
 Used: C:\Users\KarlB\OneDrive\Documents\Arduino\libraries\Adafruit_Soundboard
Multiple libraries were found for "Adafruit_NeoPixel.h"
 Used: C:\Users\KarlB\OneDrive\Documents\Arduino\libraries\Adafruit_NewPixel
Multiple libraries were found for "SoftwareSerial.h"
 Used: C:\Program
exit status 1
Error compiling for board Arduino Nano.

Thanks
Karl

acfq48, 2019-09-21:
I was having similar problems and sometimes you just need to spend some
time and clean up your libraries.  Stay tuned.  I'm currently coding in all
of the video game weapons.  I just need to finish up some final wav files
to fit everything onto the adafruit board.

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

kbritton87, 2019-09-21:
Cool sounds good. I am new to do this and decided to do this as my first project, maybe a bit optimsitc, but trying to learn as I go. I will have a look through it just keep saying the function has multiple definitions, so not really sure how to fix this.

acfq48, 2019-09-21:
It probably means that you have multiple files in your library that have
the exact same .h name.  I recommend copying everything out into a new file
and slowly putting everything back in.  Checking for duplicates along the
way.

Also, if you're brand new, this is a pretty complicated project.  First
thing to do is to get the libraries and code set up correctly.  If you
compile the base code with no errors next wire up all of your switches and
one or two of the easiest to connect lights.  Since the lights are
addressable neo pixels, if you don't get the first one right, everything in
line behind it won't work.  The switch that starts the pack is the most
important.  No other buttons with work without it.  Once you get a few
lights working, then build out all of the lights and lastly do the sound
board.  It's also helpful to solder up an adafruit jewel with the power,
ground and data lines and then go around and test all of the different data
out pins for the neo pixels.  This will help you know, which line should go
with which just incase the pinout diagram is unclear.

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

ericbanker, 2019-09-22:
It does sound like you have multiple libraries with the same names. One option is to change the directory for libraries in the Arduino ide and then start bringing the libs needed in one by one. This project does not need many. Starting fresh seems like a good try and if that doesn't work you can always set it back to what it was before.

I'd recommend starting with the spirit minimal setup if you are very new to all this. Once that is working move on to full code.

kbritton87, 2019-09-22:
Thanks Guys,

I will start over and update the library slowly. See how that does!

Closed 2019-11-19.

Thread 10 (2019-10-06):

Switch not working

J-to-the-R, 2019-10-06:
I have hooked up everything and when wire by wire to make sure I wired everything correctly. No luck when a switch on the start up switch.

I also started from the beginning and tested the simplified Spirit version with just the two pins. That one works from me. When I attempt the more advance one with the switches I can not seem to be able to turn on the lights after turning on the start up switch.

Any recommendations? Thank you.

acfq48, 2019-10-06:
It's rare, but did you try changing out arduino boards?  The key to getting
this project or really any project working is to get one light and one
switch up and going.  The best thing that I can say is to remove everything
except for the start up switch and the cyclotron lights.  Follow the pinout
guide and try to get those items working.  If that doesn't work for you
send us pictures and well figure it out.  Many pictures that are close up
shots to see the numbers on the board.

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

CountDeMonet, 2019-10-06:
acfq48 is right, start simply. Which version of the full code are you going for? If it's the one with the bar graph it won't get past the initialization without the sx1509 initializing properly. I think that's the only blocking component in the code base now. If you don't have that hooked up yet and you are using that code that could be the issue.

Simplifying down to the base start switch and cyclotron lights is a great idea and a good thing to start building on.

acfq48, 2019-10-06:
Eric,

I'm almost finished with the pack upgrades!  I'll send it to you once it's
finished but it adds the three additional weapons from the video game.
You'll need to add one additional button to the wand but I've been able to
compress all of the sound files (44 in total) plus 5 songs down to 14mb.
Ive still got a few more tweeks to do, maybe increase the quality for a
sound file or two, but I definitely recommend the upgrade.  The LCD screen
on the pack is alot of fun too and worth trying out.  You also may need to
upgrade to the mega.  My code runs on a mega but I'm sure you can figure it
out.

Best,

Alex

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

J-to-the-R, 2019-10-06:
That was exactly the issue. I was attempting to use the bar graph one without the sx1509 connected. Thanks. I testing the one without the graph and it worked as expected. Thanks you. Awesome project. Thanks again for putting this all together.

Closed 2019-10-06.

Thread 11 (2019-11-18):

Sound won't trigger it.

xblix, 2019-11-18:
@fstanley28    how you fix your sound problem finaly.

same situtation.

all wires look perfectly hook up to the right pin.

i can trigger by ground pin all  but via uart....no sound and no trigger

any clue?

Just an update on progress. Got the sound working. Everything is firing as it should! Now to put everything together for the finished pack. I appreciate everyone’s help here.

_Originally posted by @fstanley28 in https://github.com/CountDeMonet/ArduinoProtonPack/issues/5#issuecomment-461767544_

fstanley28, 2019-11-18:
I forget exactly what I did. I believe though that I double checked everything and reloaded the sound files onto the soundboard and that fixed it.

CountDeMonet, 2019-11-18:
The pack code does not log to serial out which is why it is not doing a Serial.begin(115200);

Since you have the menucommands sketch working that is great. What is not clear from your video is what the proton pack code is doing. Are you getting any lights for the cyclotron and powercell when you flip on the main switch (pin 8)?

xblix, 2019-11-18:
Yes all my lights and switchs work and react like original code suppose.

CountDeMonet, 2019-11-18:
using the menucommands sketch I want you to type the list command (L) and then copy and paste the results into this thread

xblix, 2019-11-18:
I forget than i convert all .WAV on .OGG for save space on soundboard. After changing all .wav in .ogg ib the code all perfectly work now. Thanks @CountDeMonet for point me out the files list trick.

One thing not work properly is the vent light. The vent light show up only 2 second instead to show up for the entire venting sound time...any clue to augmented times the vent light show up in the code ?

CountDeMonet, 2019-11-18:
that is odd. The venting lights are controlled by the isVenting boolean variable. That is only set to false on startup and when the booting animation is complete so you should see the lights on for the entire boot animation. Can you take a quick video of what is currently happening?

xblix, 2019-11-18:
its look like the "vent animation" stop adtern1nsecond instead during all "vent sound" time
https://youtu.be/t5wr8_8CiaI

CountDeMonet, 2019-11-19:
Well it's not actually doing the full reset animation and looks like it does one second of the reset then back to the standard. Can you post the code you are using? Looks like you had to make some mods to it for that config.

xblix, 2019-11-19:
yellow cycle suppose to show too but no yellow

https://pastebin.com/1qScEVrw

CountDeMonet, 2019-11-19:
ah, I think I figured out what is going on. You are using 3 neopixels for the powercell animation. If you look at how the animations works they are timed with the sounds using intervals based off the number of neopixels in the animation. In this case the boot animation as that is the one triggered on a "venting". In the original configuration there are 14 neopixels in the powercell. That is the one that is dictating how long to "vent" for.

void powerSequenceBoot(unsigned long currentMillis) // function in question.

In the main powercell boot animation I have 14 neopixels involved and an update interval of 60 seconds. The animation starts will all empty and then does a follow pattern stopping at the last lights until all lights in the powercell are on. At 60ms with 14 neopixels that's about 6 - 7 seconds which is how long the audio file is. Since you reduced the number of neopixels for the power cell you will need to change the delay to take into account the reduced number of leds.

const unsigned long pwr_boot_interval = 60;       // interval at which to cycle lights (milliseconds). Adjust this if

Just a guess but it's probably going to need to be closer to 1000 ms as with the 3 led's that leaves only 6 "frames" for the animation I believe. Could be off on that.

xblix, 2019-11-19:
i dont change the code since yesterday cause i see something...
https://youtu.be/fhZpvA5-lyI
animation its ajusted by the const number of led and works wee without soundboard connected
but with sound board connected..
 not...only 1 second

CountDeMonet, 2019-11-19:
When you are disconnecting the soundboard you are causing delays to occur due to failures to communicate with the sound board. These are the pauses each time it tries to play an audio track. If you actually disable the sound board within the code and don't attempt to play the tracks or access the play state then you will find those delays go away and the code acts the same way. The issue is the timing of the intervals and the number of led's in the animations.

xblix, 2019-11-19:
const unsigned long pwr_boot_interval = 680;

all slick now.
thanks for help and this great code @CountDeMonet

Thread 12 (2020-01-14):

Real random queuarray

xblix, 2020-01-14:
i play since several week with this code and all is so good.

But i realize than queuarray is not a real random sounds playlist. Yeah after many test its appears than the queuarray suppose to play random quote of the movie but he not did it. Its always the same order after a reset of the board.

How i can make a real random queu?

CountDeMonet, 2020-01-14:
I tried a number of things to try and randomize the sayings without much luck. The random() function on the arduino isn't as random as you would hope. I kept getting repeating quotes. The queue array was an attempt to fix that but that didn't work either but the dequeing worked great. If you want to give a go at randomizing it yourself look at this code where the dialogs are entered into the queue. If you can randomize the order placed into the queue that would do it.

`
void playDialogTrack( int playing ) {
  // if the queue is empty reseed it
  if ( dialogQueue.isEmpty() ) {
    for (int i = 1; i <= numDialog; i++) {
      dialogQueue.enqueue(i);
    }
  }

`

grogking, 2020-01-14:
One suggestion I have is using the randomSeed() funtion with the analogRead () function. Essentially, it reads an unused pin which will give it a random number from the "noise" on the unused pin to generate a seed number that then is used as a seed to start the randomizer with an actual random number.

Here is code I use for generating random blinking patterns on leds.
`//Declare and initialize LED pin variables
int LED_1 = 2;
int LED_2 = 3;
int LED_3 = 4;

//this variable will hold a random number generated by the random() function
long randomNumber;

//Set up - this is where you get things "set-up". It will only run once
void setup() {

  //setup serial communications through the USB
  Serial.begin(9600);

  //Let's print a start messgae to the serial monitor when a new sequence of random numbers starts
  Serial.println("Starting new Random Number Sequence");

  //set the LED pins as outputs
  pinMode(LED_1, OUTPUT);
  pinMode(LED_2, OUTPUT);
  pinMode(LED_3, OUTPUT);

  //Let's make it more random
  randomSeed(analogRead(A0));

}//close setup

//The loop() runs over and over again
void loop() {

  //generate a random number
  randomNumber = random(2,5);

  //display the random number on the serial monitor
  Serial.print("The Random Number is = ");
  Serial.println(randomNumber);`

xblix, 2020-01-14:
Exactly what i find too  randomSeed.
Code alonge serual print perfectly.
But integrate to the proton code, print is not random.
Close from the solution.
Perhap how i put the random number from Seed and where i put inside this :
void playDialogTrack( int playing ) {
  // if the queue is empty reseed it
  if ( dialogQueue.isEmpty() ) {
    for (int i = 1; i <= numDialog; i++) {
      dialogQueue.enqueue(i);
    }
  }

grogking, 2020-01-14:
I'm not a coding expert, self taught mostly, and its been a while since I edited this code for my pack.  However, perhaps you need to get rid of the queue, and replace it with something using something like this
long quoteNumber = 0:
void setup() {
randomSeed (analogRead (put empty pin number here);
}
void loop (){
quoteNumber = random (1,8)   // I forget how many quotes there are

}

Then have it play the quote that matches the number in quoteNumber.

xblix, 2020-01-14:
Finaly i get randomNumber "really" random inside proton code.

`  long randomNumber = 0:
void setup() {
randomSeed (analogRead (A4);

void playThemeTrack( int playing ) {
  // if the queue is empty reseed it
  if ( themeQueue.isEmpty() ) {
    for (int i = 1; i <= randomNumber; i++) {
      themeQueue.enqueue(i);
    }
  }
}
void loop (){
quoteNumber = random (1,8) // 7 quote  - Max not include

}

  `

Thanks for help guys!!!

Closed 2020-01-14.

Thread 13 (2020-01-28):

E-cig addition

fstanley28, 2020-01-28:
Has anyone tried this yet? I see there is and ino file with the relay but as for wiring I didn't see anything. Any guidance would be awesome.

CountDeMonet, 2020-01-28:
A number of people have used that code. As for wiring it up there is not much to it. The relay is a remote controlled switch so on the control side there is a ground and signal. Those connect to the arduino ground and pin 13. Then you wire the ecig up to it's separate power source and stick the relay in between the power side.  Here's an example of how it can go

https://i0.wp.com/randomnerdtutorials.com/wp-content/uploads/2016/11/Schematics.png?w=700&ssl=1

from this site https://randomnerdtutorials.com/guide-for-relay-module-with-arduino/

fstanley28, 2020-01-28:
Perfect, thank you. I am loving this build!

Closed 2020-01-28.

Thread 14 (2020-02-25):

useGameCyclotronEffect

xblix, 2020-02-25:
i try to create a second mode : slime mode.
For that i create bosonmode bool and slimemode bool for swtich true or false between both mode. Like this

`bool bosonmode = true;
bool slimemode = false;`

The code i do work super good when gamecyclotroneffect is false.
But when is true its not work.
When i switch mode from boson to slime mode, all stop (all function, not just light sequence)

There is my code part where is super good in bosonmode but not in slimemode

[slimemode.txt](https://github.com/CountDeMonet/ArduinoProtonPack/files/4251348/slimemode.txt)

Any cue what wrong? or how to achieve this for have a perfect same pathern but in green fade effect instead of red when its slimemode is true?

i try to create new function (reproduce all red function in green, create 5th and 6th case in the switch too but nothing work. Always stop work when i switch.

I know iam close to get it but i miss something for shure.

Thanks for helping

CountDeMonet, 2020-02-27:
Your code is a little over complex and is missing the default states.

`
void setCyclotronLightState(int startLed, int endLed, int state) {
  switch (state) {
    case 0: // set all leds to red
      for (int i = startLed; i <= endLed; i++) {
        if (bosonmode == true) {
          powerStick.setPixelColor(i, powerStick.Color(255, 0, 0));
        }else if (slimemode == true) {
          powerStick.setPixelColor(i, powerStick.Color(0, 255, 0));
        }else{
          powerStick.setPixelColor(i, powerStick.Color(255, 0, 0));
        }
      }
      break;
    case 1: // set all leds to orange
      for (int i = startLed; i <= endLed; i++) {
        powerStick.setPixelColor(i, powerStick.Color(255, 90, 0));
      }
      break;
    case 2: // set all leds off
      for (int i = startLed; i <= endLed; i++) {
        powerStick.setPixelColor(i, 0);
      }
      break;
    case 3: // fade all leds from red
      for (int i = startLed; i <= endLed; i++) {
        if (cyclotronRunningFadeOut >= 0) {
          if (bosonmode == true) {
            powerStick.setPixelColor(i, 255 * cyclotronRunningFadeOut / 255, 0, 0);
          } else if (slimemode == true) {
            powerStick.setPixelColor(i, 255 * cyclotronRunningFadeOut / 0, 255, 0);
          } else{
            powerStick.setPixelColor(i, 255 * cyclotronRunningFadeOut / 255, 0, 0);
          }
          cyclotronRunningFadeOut--;
        } else {
          powerStick.setPixelColor(i, 0);
        }
      }
      break;
    case 4: // fade all leds to red
      for (int i = startLed; i <= endLed; i++) {
        if (cyclotronRunningFadeIn < 255) {
          if (bosonmode == true) {
            powerStick.setPixelColor(i, 255 * cyclotronRunningFadeIn / 255, 0, 0);
          }else if (slimemode == true) {
            powerStick.setPixelColor(i, 255 * cyclotronRunningFadeIn / 255, 0, 0);
          }else{
            powerStick.setPixelColor(i, 255 * cyclotronRunningFadeIn / 255, 0, 0);
          }
          cyclotronRunningFadeIn++;
        } else {
          powerStick.setPixelColor(i, powerStick.Color(255, 0, 0));
        }
      }
      break;
  }
}
`

xblix, 2020-02-27:
No, cleaned text its block too.
Its look like fade effect its linked to something else.
iam thinking with a simple if or if else like you do i get it.
But something other block.

acfq48, 2020-02-27:
I've been working on this very project for a few months now on and off.
Got side tracked for a bit but I'm getting back on track.  I was able to
make all 4 modes with secondary fire modes for each weapon.  I've got to
debug the code to get out an issue that I've been having with boot up but I
should have that fixed within a few weeks if you care to wait.  It does run
on a Mega but might run just fine on a nano.  I haven't tested that out
yet.  If you want to wait I can send it to you when I finish.  Count, if
you want to help me debug I can send it to you in the meantime.

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

xblix, 2020-02-27:
> I've been working on this very project for a few months now on and off. Got side tracked for a bit but I'm getting back on track. I was able to make all 4 modes with secondary fire modes for each weapon. I've got to debug the code to get out an issue that I've been having with boot up but I should have that fixed within a few weeks if you care to wait. It does run on a Mega but might run just fine on a nano. I haven't tested that out yet. If you want to wait I can send it to you when I finish. Count, if you want to help me debug I can send it to you in the meantime.
> […](#)
> On Thu, Feb 27, 2020, 10:05 AM xblix ***@***.***> wrote: No, cleaned text its block too. Its look like fade effect its linked to something else. iam thinking with a simple if or if else like you do i get it. But something other block. — You are receiving this because you are subscribed to this thread. Reply to this email directly, view it on GitHub <#14?email_source=notifications&email_token=AH7NHB66O4GQJQJSQTDI2GTRE76ERA5CNFSM4K3PGGRKYY3PNVWWK3TUL52HS4DFVREXG43VMVBW63LNMVXHJKTDN5WW2ZLOORPWSZGOENFLAXA#issuecomment-592097372>, or unsubscribe <https://github.com/notifications/unsubscribe-auth/AH7NHB7AA3DLTGBNU5SBES3RE76ERANCNFSM4K3PGGRA> .

Cool. Same 4 mode work with secondary fire for me too and boot works perfect as iam stock for fadegame effect. But normal boot work in for mode for me.
If you have time share your code i can try debug for you too. :)

LastrisOrt, 2020-09-30:
Hey guys, what's the state here?
I'm currently assembling my proton pack. Of course, if it's possible, I would like to add the video game mode as well. What would be really cool is another (hidden) switch to toggle between movie  Cyclotron (without fading) and video game Cyclotron (with fading and four color modes).
Any ideas how we get this working?

CountDeMonet, 2020-09-30:
If you are using an arduino mega with tons of pins you could just add a switch to the pack somewhere. I use these

https://www.amazon.com/gp/product/B01N2U8PK0/ref=ppx_yo_dt_b_search_asin_title?ie=UTF8&psc=1

Just read the pin high or low in the main loop then set the value of the setting bools. Then you have the ability to toggle on and off. Should even work as the pack is running.

const bool useGameCyclotronEffect = true;   // set this to true to get the fading previous cyclotron light in the idle sequence
const bool useCyclotronFadeInEffect = false; // Instead of the yellow alternate flashing on boot/vent this fades the cyclotron in from off to red
const bool useDialogTracks = true;          // set to true if you want the dialog tracks to play after firing for 5 seconds

acfq48, 2020-10-01:
I've almost finished a large update on the code.  It adds all four video
game modes along with a secret menu for selecting different animation
speeds, colors, sounds etc.  I recently got a new job but it's time for me
to dive back into the code.  It should work on a regular Count DeMonet
setup with maybe just one more button.  You do need an arduino Mega though.

<http://www.avg.com/email-signature?utm_medium=email&utm_source=link&utm_campaign=sig-email&utm_content=webmail>
Virus-free.
www.avg.com
<http://www.avg.com/email-signature?utm_medium=email&utm_source=link&utm_campaign=sig-email&utm_content=webmail>
<#DAB4FAD8-2DD7-40BB-A1B8-4E2AA1F9FDF2>

On Wed, Sep 30, 2020 at 9:02 AM Eric Banker <notifications@github.com>
wrote:

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

LastrisOrt, 2020-10-01:
That's Great news. Looking forward to test your code. :-)

acfq48, 2020-10-02:
The memory is important.  My code is ok but it isn't the most optimized out
there.  Hopefully, I'll get this version done before the end of the year
but having a Mega certainly doesn't hurt.

<http://www.avg.com/email-signature?utm_medium=email&utm_source=link&utm_campaign=sig-email&utm_content=webmail>
Virus-free.
www.avg.com
<http://www.avg.com/email-signature?utm_medium=email&utm_source=link&utm_campaign=sig-email&utm_content=webmail>
<#DAB4FAD8-2DD7-40BB-A1B8-4E2AA1F9FDF2>

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

CountDeMonet, 2020-10-03:
The nano is close to being out of pins and memory on the latest code. I had to go to lengths to get the memory usage down. If I was starting this project now, no question, I would use a mega. The only reason I went with the nano to begin with was because the original plan was to put it in the wand. When it turned out that the serial communication to the audio board and pack lights was scrambled due to noise I had to move the arduino to the pack. I had a really nice nano daughter board developed and ready for wand too.

Closed 2020-11-15.

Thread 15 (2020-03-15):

queue array not working

JOBLOW20, 2020-03-15:
I've been using the code ''neutrino wand with graph''  and so far everything is working great.  The only thing i'm having a problem with is the queue array. For example in the code if i replace the '' playDialogTrack(playing); ''on line 397 with ''playAudio (boxTrack, playing);'' it will then play the boxtrack normally when firing between 5 to 10 seconds . What could be causing the queueArray to not work?  I am using a mega 2560 R3 and the adafruit soundboard.

CountDeMonet, 2020-03-15:
What is the problem you are having when playDialogTrack is called? Is nothing happening or are you getting a random sound?

JOBLOW20, 2020-03-15:
When the lights start flashing faster(between 5-10 seconds of holding the fire button) i let go of the firing button and the lights pause for a second and then the startup sequence happens (lights and sound).

CountDeMonet, 2020-03-15:
That is really strange. It's clearly resetting the arduino. Are you using the version of the library I have here on github or the one available in the github libraries?

https://github.com/CountDeMonet/ArduinoProtonPack/tree/master/Arduino/libraries/QueueArray

Generally when there is a reset I would look at input voltages but in this case there is just nothing that dequeueing a string would do to stress the hardware. Plus the mega has way more memory and power than the nano.

JOBLOW20, 2020-03-17:
I dont know why, but i took for granted that my source of 5 volts was ok. Turns out my power supply was to low for my board. The low limit is 6 volts. So thanks for the hint. Pretty sure its going to workout now with the right voltage supply. Thanks for the support, its really appreciated.

JOBLOW20, 2020-03-19:
The voltage was not the problem, i am going to uninstall my Arduino software and reinstall with the right libraries...

JOBLOW20, 2020-03-19:
Uninstalled my arduino software, reinstalled it and loaded the right libraries and it is still doing the same thing...  I should be receiving my nano board soon and will try with it... I'm wondering if the preferences file is causing my problem...

acfq48, 2020-03-19:
Also, double check which arduino version you're using.  I've had issues
with boards that required me to open an older version of the software to
upload my code.  It looks like I've saved version 1.6.3 and 1.8.4 for use
with my proton pack.

See if that works for you.

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

xblix, 2020-03-19:
can you post all your code that help to see

JOBLOW20, 2020-03-19:
I am using the 1.8.12 version and here is the code used:

#include <QueueArray.h>

#include <Wire.h> // Include the I2C library (required)
#include <SparkFunSX1509.h> // Include SX1509 library

// for the sound board
#include <SoftwareSerial.h>
#include "Adafruit_Soundboard.h"

#include <Adafruit_NeoPixel.h>

// for led triggers
#define HIGH 0x1
#define LOW  0x0

// SX1509 I2C address (set by ADDR1 and ADDR0 (00 by default):
const byte SX1509_ADDRESS = 0x3E;  // SX1509 I2C address
SX1509 io; // Create an SX1509 object to be used throughout

// bargraph helper variables
int seq_1_current = 0;  // current led in sequence 1
const int num_led = 15; // total number of leds in bar graph

// SX1509 pin definitions for the leds on the graph:
const byte SX1509_BAR_01 = 0;
const byte SX1509_BAR_02 = 1;
const byte SX1509_BAR_03 = 2;
const byte SX1509_BAR_04 = 3;
const byte SX1509_BAR_05 = 4;
const byte SX1509_BAR_06 = 5;
const byte SX1509_BAR_07 = 6;
const byte SX1509_BAR_08 = 7;
const byte SX1509_BAR_09 = 8;
const byte SX1509_BAR_10 = 9;
const byte SX1509_BAR_11 = 10;
const byte SX1509_BAR_12 = 11;
const byte SX1509_BAR_13 = 12;
const byte SX1509_BAR_14 = 13;
const byte SX1509_BAR_15 = 14;

// neopixel pins / setup
#define NEO_POWER 2 // for cyclotron and powercell
Adafruit_NeoPixel powerStick = Adafruit_NeoPixel(48, NEO_POWER, NEO_GRB + NEO_KHZ800);

#define NEO_NOSE 3 // for nose of wand
Adafruit_NeoPixel noseJewel = Adafruit_NeoPixel(7, NEO_NOSE, NEO_GRB + NEO_KHZ800);

#define NEO_WAND 4 // for nose of wand
Adafruit_NeoPixel wandLights = Adafruit_NeoPixel(4, NEO_WAND, NEO_GRB + NEO_KHZ800);

// LED indexes into the neopixel powerstick chain for the cyclotron. Each stick has 8 neopixels for a total of
// 16 with an index starting at 0. These offsets are because my powercell window only shows 13 leds. If you can show more
// change the offset index and powercell count to get more or less lit.
const int powercellLedCount = 14;                                         // total number of led's in the animation
const int powercellIndexOffset = 1;                                       // first led offset into the led chain for the animation

// These are the indexes for the led's on the chain. Each jewel has 7 LEDs. If you are using a single neopixel or
// some other neopixel configuration you will need to update these indexes to match where things are in the chain
int c1Start = 16;
int c1End = 22;
int c2Start = 23;
int c2End = 29;
int c3Start = 30;
int c3End = 36;
int c4Start = 37;
int c4End = 43;
int ventStart = 44;
int ventEnd = 47;

// inputs for switches and buttons
const int THEME_SWITCH = 5;
const int STARTUP_SWITCH = 6;
const int SAFETY_SWITCH = 7;
const int FIRE_BUTTON = 8;

// soundboard pins and setup
#define SFX_RST 9
#define SFX_RX 10
#define SFX_TX 11
const int ACT = 12;    // this allows us to know if the audio is playing

SoftwareSerial ss = SoftwareSerial(SFX_TX, SFX_RX);
Adafruit_Soundboard sfx = Adafruit_Soundboard( &ss, NULL, SFX_RST);

// ##############################
// available options
// ##############################
const bool useGameCyclotronEffect = true;   // set this to true to get the fading previous cyclotron light in the idle sequence
const bool useCyclotronFadeInEffect = false; // Instead of the yellow alternate flashing on boot/vent this fades the cyclotron in from off to red
const bool useDialogTracks = true;          // set to true if you want the dialog tracks to play after firing for 5 seconds

// Possible Pack states
bool powerBooted = false;   // has the pack booted up
bool isFiring = false;      // keeps track of the firing state
bool shouldWarn = false;    // track the warning state for alert audio
bool shuttingDown = false;  // is the pack in the process of shutting down
bool poweredDown = true;    // is the pack powered down
bool venting = false;       // is the pack venting

// physical switch states
bool startup = false;
bool theme = false;
bool safety = false;
bool fire = false;
bool warning = false;

// audio track names on soundboard
char startupTrack[] =   "T00     WAV";
char blastTrack[] =     "T01     WAV";
char endTrack[] =       "T02     WAV";
char idleTrack[] =      "T03     WAV";
char shutdownTrack[] =  "T04     WAV";
char clickTrack[] =     "T05     WAV";
char chargeTrack[] =    "T06     WAV";
char warnTrack[] =      "T07     WAV";
char ventTrack[] =      "T08     WAV";
char texTrack[] =       "T09     WAV";
char choreTrack[] =     "T10     WAV";
char toolsTrack[] =     "T11     WAV";
char listenTrack[] =    "T12     WAV";
char thatTrack[] =      "T13     WAV";
char neutronizedTrack[]="T14     WAV";
char boxTrack[] =       "T15     WAV";
char themeTrack[] =     "T16     OGG";

// this queue holds a shuffled list of dialog tracks we can pull from so we don't
// play the same ones twice
QueueArray <int> dialogQueue;
int numDialog = 7;

// timer trigger times/states
unsigned long firingStateMillis;
const unsigned long firingWarmWaitTime = 5000;  // how long to hold down fire for lights to speed up
const unsigned long firingWarnWaitTime = 10000;  // how long to hold down fire before warning sounds

// Arduino setup function
void setup() {
  // softwareserial at 9600 baud for the audio board
  ss.begin(9600);

  // set act modes for the fx board
  pinMode(ACT, INPUT);

  // configure nose jewel
  noseJewel.begin();
  noseJewel.setBrightness(100);
  noseJewel.show(); // Initialize all pixels to 'off'

  // configure powercell/cyclotron
  powerStick.begin();
  powerStick.setBrightness(75);
  powerStick.show(); // Initialize all pixels to 'off'

  // configure wand lights
  wandLights.begin();
  wandLights.setBrightness(75);
  wandLights.show();

  // set the modes for the switches/buttons
  pinMode(THEME_SWITCH, INPUT);
  digitalWrite(THEME_SWITCH, HIGH);
  pinMode(STARTUP_SWITCH, INPUT);
  digitalWrite(STARTUP_SWITCH, HIGH);
  pinMode(SAFETY_SWITCH, INPUT);
  digitalWrite(SAFETY_SWITCH, HIGH);
  pinMode(FIRE_BUTTON, INPUT);
  digitalWrite(FIRE_BUTTON, HIGH);

    // Call io.begin(<address>) to initialize the SX1509. If it
  // successfully communicates, it'll return 1.
  if (!io.begin(SX1509_ADDRESS)) {
    while (1) ; // If we fail to communicate, loop forever for now but it would be nice to warn the user somehow
  }

  // configuration for the bargraph LED's
  io.pinMode(SX1509_BAR_01, OUTPUT);
  io.pinMode(SX1509_BAR_02, OUTPUT);
  io.pinMode(SX1509_BAR_03, OUTPUT);
  io.pinMode(SX1509_BAR_04, OUTPUT);
  io.pinMode(SX1509_BAR_05, OUTPUT);
  io.pinMode(SX1509_BAR_06, OUTPUT);
  io.pinMode(SX1509_BAR_07, OUTPUT);
  io.pinMode(SX1509_BAR_08, OUTPUT);
  io.pinMode(SX1509_BAR_09, OUTPUT);
  io.pinMode(SX1509_BAR_10, OUTPUT);
  io.pinMode(SX1509_BAR_11, OUTPUT);
  io.pinMode(SX1509_BAR_12, OUTPUT);
  io.pinMode(SX1509_BAR_13, OUTPUT);
  io.pinMode(SX1509_BAR_14, OUTPUT);
  io.pinMode(SX1509_BAR_15, OUTPUT);

  // set everything off initially
  shutdown_leds();
}

/* ************* Audio Board Helper Functions ************* */
// helper function to play a track by name on the audio board
void playAudio( char* trackname, int playing ) {
  // stop track if one is going
  if (playing == 0) {
    sfx.stop();
  }

  // now go play
  if (sfx.playTrack(trackname)) {
    sfx.unpause();
  }
}

void playDialogTrack( int playing ){
  // if the queue is empty reseed it
  if ( dialogQueue.isEmpty() ){
    for (int i=1; i<=numDialog; i++){
      dialogQueue.enqueue(i);
    }
  }

  switch (dialogQueue.dequeue()){
    case (1):
      playAudio(texTrack, playing);
      break;
    case (2):
      playAudio(listenTrack, playing);
      break;
    case (3):
      playAudio(choreTrack, playing);
      break;
    case (4):
      playAudio(boxTrack, playing);
      break;
    case (5):
      playAudio(thatTrack, playing);
      break;
    case (6):
      playAudio(neutronizedTrack, playing);
      break;
    case (7):
      playAudio(toolsTrack, playing);
      break;
    default:
      playAudio(endTrack, playing);
      break;
  }
}

/* ************* Main Loop ************* */
int cyclotronRunningFadeOut = 255;  // we reset this variable every time we change the cyclotron index so the fade effect works
int cyclotronRunningFadeIn = 0;     // we reset this to 0 to fade the cyclotron in from nothing

// intervals that can be adjusted in real time to speed up animations
unsigned long pwr_interval = 60;        // interval at which to cycle lights for the powercell. We update this in the loop to speed up the animation so must be declared here (milliseconds)
unsigned long cyc_interval = 1000;      // interval at which to cycle lights for the cyclotron.
unsigned long cyc_fade_interval = 15;   // fade the inactive cyclotron to light to nothing
unsigned long firing_interval = 40;     // interval at which to cycle firing lights on the bargraph. We update this in the loop to speed up the animation so must be declared here (milliseconds).

void loop() {
  // get the current time
  unsigned long currentMillis = millis();

  // find out of the audio board is playing audio
  int playing = digitalRead(ACT);

  // get the current switch states
  int theme_switch = digitalRead(THEME_SWITCH);

  // if the theme switch has recently changed from off to on we
  // should play the full ghostbusters theme song
  if (theme_switch == 1) {
    if (theme == false) {
      playAudio(boxTrack, playing);
      theme = true;
    }
  } else {
    theme = false;
  }
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

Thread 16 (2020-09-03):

Ecig wiring

Tom-Neverwinter, 2020-09-03:
I am going to go out on a limb and assume this is the circuit for the ecig version or close enough.
https://www.gbfans.com/forum/viewtopic.php?t=36943&start=210

CountDeMonet, 2020-09-03:
Since the code supports relays yes, anything after the relay is good as it is a completely different circuit. The mighty part is replaced by the arduino pin 13 which goes to the en of the relay in that diagram.

Closed 2020-11-15.

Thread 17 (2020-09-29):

Outages and resets

LastrisOrt, 2020-09-29:
Hi,
I've just begun building the proton pack using your arduino code. When I push the fire-button, all lights are stopping for about a second before moving on. Same goes when releasing the fire-button or when reaching the 10 second limit. When it "overheats" it shuts itself down and boots again (can't tell you about the sound at the moment, I'm troubleshooting the lights first).
Things I've done so far:
- Used three different arduinos (Nano Clone, Nano Clone, Arduino Uno)
- Checked the wiring
- Changed the power supply (but always only using 5V from USB, whether it's from my MacBook or from power outlet)
- Everything powered by the USB-plug OR the 5V Vin (tested both).
- Used different versions of Arduino software 1.8.13, 1.8.12, 1.8.4 (it solved a similar problem in another thread), 1.8.5.

I hope to get some help here because I don't know what else it might be.
Thank you in advance

CountDeMonet, 2020-09-29:
If you don't have the audio board connected then you need to comment out some code cause the audio board code is blocking.

1. comment out the contents of the playAudio function but leave the function declaration.
2. in the main loop remove the read of the act pin.
// find out of the audio board is playing audio
  int playing = 1; //digitalRead(ACT);

I think that is enough to stop the lagging caused by the blocking code in the library. Once the audio board is connected and the files exist on it all will be well

LastrisOrt, 2020-09-29:
Awesome, thank you very much for your quick help! It worked! :-)

LastrisOrt, 2020-09-30:
It's all about the complete setup ;-)

Closed 2020-09-30.

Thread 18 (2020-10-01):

Idea collection

LastrisOrt, 2020-10-01:
As I'm quite new to GitHub and the ArduinoProtonPack, I'm not really sure how to open a thread, so please forgive me.
I would like to open some kind of idea collection what could be a ArduinoProtonPack 2.0:

**Switches on the motherboard (or in a small printed enclosure) not visible when wearing the proton pack:**
- Switch to mute/unmute the pack (it's just a switch to disconnect the power from the amplifier, easy to realize)
- Potentiometer to adjust the volume (no need to explain this ;-) )
- Potentiometer to adjust the LED brightness (for example when in a showcase at home or in a dark environment).
- Switch to toggle between GameCyclotron and MovieCyclotron
- Switch to toggle between "Cyclotron fading" in and "Cyclotron blinking on start"
- Switch to enable/disable the dialog tracks

**Buttons visible on the wand:**
- Intensify button to skip to another music track(s) when in theme mode
- Button at the front of the wand skips through different modes when switched to GameCyclotron.

Do you have anything else what could be interesting here?
Maybe we can get some people together and work on it?
Looking forward for your comments/suggestions

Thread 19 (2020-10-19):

Uploading the code

bunionhead, 2020-10-19:
Hi, is there anyone that can help me with a step by step guide and how to upload everything to the Arduino please?

Want to do the wand with graph and ecig plus add the sparks fun board.
Bit of a noob when it comes to Arduino but I’m good and following instructions
Thanks

acfq48, 2020-10-25:
I'm always willing to help of you have any questions.  You'll want to get
all of the materials on the list first.

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

pe547c, 2020-11-14:
I just finished buying all of the electronics and I am working on getting the code to operate properly.

I am getting an error "QuerryArray" was not declared on line 113 of the Wand with no Bar Graph code.  There are a bunch of warnings above that but the QuerryArray shut the code down.

I did a straight Copy/Paste from the file into the Arduino IDE 1.8.13.

Any help would be appreciated, i have not yet used Arduino.  I do have MatLab experience from college but that is about it.

Thanks

CountDeMonet, 2020-11-14:
you are missing the libraries needed for the code to work. Here is some information on Libraries and where they are installed

https://www.arduino.cc/en/Guide/Libraries

Look at the manual installation area. These are the libraries you need to put in the correct location

https://github.com/CountDeMonet/ArduinoProtonPack/tree/master/Arduino/libraries

pe547c, 2020-11-14:
In the Libraries Folder I don't see a download option in order to get the .zip file.

CountDeMonet, 2020-11-14:
On the code page there is a download repository button. Download the whole repository not just individual files. Then your life will be much easier

pe547c, 2020-11-14:
That worked like a charm :)

Closed 2020-11-15.

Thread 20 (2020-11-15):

Proton Pack Circuit Diagram - No Bargraph Schematic

pe547c, 2020-11-15:
In the schematic I see 4 additional LEDs on the Wand and 4 additional LEDs on the Proton Pack.  Does the code cover for these and if so where do you put them?

I noticed on the video there was a blue light in the wand as well as button lights are those these LEDs?

Separate question, on the Schematic the Amplifier looks different than the one on the order sheet.  Should I be using 2 of the ones from the order sheet or could you link the model number for the one from the schematic?

Thanks a ton for this site, i am new to Arduino and this is a crash course per say :)

CountDeMonet, 2020-11-15:
In addition to the neopixel jewel, the wand has the sloblo led, top indicator led, base box front led, and vent light led. On mine I used the single neopixels for them. There are mounts for these led's in the 3d files. 
I used several amps while designing this thing. TBH I would recommend finding something more powerful if you like volume out of it. The amps/speakers can be hooked up separately as they are their own circuit so you can substitute whatever you want. This was the amp I ultimately went with 

https://www.amazon.com/gp/product/B00N42NP6W

CountDeMonet, 2020-11-15:
In the pack the additional led's are for the venting. If you have not seen them yet I have videos from the development of the electronics in a playlist here

https://www.youtube.com/playlist?list=PLBhSpY0c5z2dxnJxVPDHdh-QpJ_xY3YSR

CountDeMonet, 2020-11-15:
You can also find a ton of info in the build thread

https://www.gbfans.com/forum/viewtopic.php?f=2&t=43273

pe547c, 2020-11-23:
I found it, all is soldered and in place now :)  thanks.

Closed 2020-11-23.

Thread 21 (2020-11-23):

Getting Arduino to execute

pe547c, 2020-11-23:
So i have everything wired up from the 'No Bargraph" wiring diagram.

I checked with Multimeter and every V is 4.9 to 5.1 Volts and every Data Input is 0.7V.

Toggle Switches are either 0V or .6V depending on the switch position.

I loaded the Code to the Arduino and it loaded successfully.

Problem is when i put power to the system, and flip any/all toggle switches nothing happens.  I rechecked all the Voltages and it is still as i stated above.  Arduino loads fine so i don't think that is broken.  Not sure what is wrong.

Any help would be very welcome :)

Thanks

unrepentant64, 2021-01-23:
I have a similar issue with another proton pack build that I found on Github.  Did you get any input, or solution to your project?  I replicated this build as well (as an alternative) and most of it works...

CountDeMonet, 2021-01-25:
I think discussion on pe547's issues moved over to the build thread on gbfans

https://www.gbfans.com/forum/viewtopic.php?f=2&t=43273

There is a lot of information there and the last few pages are mainly helping other people with the build

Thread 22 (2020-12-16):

Changing the wand LED's

bunionhead, 2020-12-16:
Hi guys, I've uploaded the code and everything is running great.
I'm just wondering if it's possible to change the 4 LED's in the wand in what they do? say for Example I'd like to make the white one flash? I've looked through the code and there seems to be a part where it mentions a white flashing LED but don't know what to do or Is this for a 5th LED that needs to be added?
Thanks guys

CountDeMonet, 2021-01-25:
Sorry I'm just seeing this. The wand chain is pretty simple to add lights to if you want. The wand lights are in their own chain so you would just add a light onto the chain and put it in the wand wherever you want.  On this line in the code update the number 4 to the number of led's in the chain. If you just add one make it a 5.

Adafruit_NeoPixel wandLights = Adafruit_NeoPixel(4, NEO_WAND, NEO_GRB + NEO_KHZ800);

The lights are referenced in the order they are in the chain. For example the slo blo light is number 3 in the chain so to reference it and make it turn on you call the wand light helper function

setWandLightState(3, 0, 0); //set sloblow red

That function has a number of options for setting lights to specific colors and flashing and stuff

void setWandLightState(int lednum, int state, unsigned long currentMillis){

first param is the index of the light you want to control. This is indexed 0 so the first led is 0. The state can be

0: // set led red
1: // set led white
2: // set led orange
3: // set led blue
4: // set led off
5: // fast white flashing
6: // slower orange flashing
7: // medium red flashing
8: // fast red flashing

The last parameter is used for the flashing options. The setWandLight is only used in the main loop so if you are doing a flashing option you just include the existing param currentMillis. There are lots of examples in the code to show how to use it.

bunionhead, 2021-01-31:
Thanks for the reply. Maybe I should have explained I’m a bit of a noob at coding.
I understand the bit where you change the number to add more leds and setting the state in way(i think) but it’s the getting them to flash.

Basically I want to add 2 more leds that are white that flash alternatively

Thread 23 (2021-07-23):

Connect to the spengler wand?

alpenserge, 2021-07-23:
Great project! Thank you very much fot this.

I think about to cut some corners with the spengler wand. Maybe you have an idea to wiring this to the pack?

Thank you!

CountDeMonet, 2021-07-27:
I'm sorry but I have not seen the internals to the Spengler wand and can't offer any real suggestions. Maybe someone else can.

CountDeMonet, 2021-12-21:
I have a spengler wand now and might look into this. I did also fund the hasbro pack so will be getting one of those at some point too.

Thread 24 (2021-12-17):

Wand board with bar graph

dougbevan, 2021-12-17:
Great project, in many ways better than the pre-made kits, and tweak-able!

Did you happen to do a wand io board that includes the bar graph?  I'm putting together the whole project including bar graph, and it would be great to have a board that includes it.

CountDeMonet, 2021-12-17:
Glad you are finding it useful. I never did get around to ordering the boards and finishing that. I ran out of time and ended up wiring them up manually with proto boards. It would be a fun project to design that but I didn't have time.

These are the only images I have of the bargraph proto board I built. Worked well.
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

dougbevan, 2021-12-17:
Appreciate the images and response.  Yes, it's a great project and a fantastic contribution to the community.

I'm fine with programming but have never tried my hand at Eagle.  I did order the boards you designed to give them a try, but I will try extending the wand.io board to include signals/power for the bar graph.

Closed 2021-12-17.

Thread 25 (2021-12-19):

Bar graph code / execution

dougbevan, 2021-12-19:
Greetings!

Having some trouble getting the barograph code to work....

I believe I have everything wired correctly and double-checked the solder joints.

It works fine with the "neutrona_wand" file with no barograph.  As soon as I upload the barograph code, nothing works.

I tried to comment out these lines to see if there was some problem initializing the SX1509:

  // Call io.begin(<address>) to initialize the SX1509. If it
  // successfully communicates, it'll return 1.
  if (!io.begin(SX1509_ADDRESS)) {
    while (1) ; // If we fail to communicate, loop forever for now but it would be nice to warn the user somehow
  }

However, even with these lines commented, the code ceases to function.

Any thoughts on what's going on here?

dougbevan, 2021-12-19:
I got this working.  It turned out to be a couple of things:

- I had a grounding pin in the wrong place
- I had a bad solder joint on the 3.3V line

One other small issue is that the LED bar graph isn't very bright, compared to the neopixel devices.  Any idea why this is, or how to make them brighter (or source a brighter bar?).

CountDeMonet, 2021-12-20:
Glad you got it figured out. Bad solder joints can kill you with this project. My pack is down at the moment due to a bad connection somewhere but I have not traced it down yet. I'm going to have to resolder each pin which is a pain while it's in the pack.

The sx1509 is a handy for the job but it is an old solution now. There are several options now for led breakout boards that utilize higher voltages as well as higher current to make the leds brighter. That said you can try removing the resisters from the bar graph. This is going to cause the bar graph to pull the most current available from the sx1509 but it shouldn't be an issue. my eyes are sensitive to led light so I prefer them more muted but I also set the level for a safe current from the breakout board. I know others have gone without the resistors and been happy.

dougbevan, 2021-12-20:
Indeed.  Sorry to hear about your pack fault -- they can be a bugger to track down, particularly when things look find and they are not.

If you were doing the bar graph today, what solutions would you look at?  Perhaps I'll update this.  I also considered swapping the nano for a mega and running the graph directly.

CountDeMonet, 2021-12-20:
When I started the project I intended to use a nano in the wand and a nano in the pack to run the major bits separately. As time ran down and the issues came up (length of the cable to the wand and communication cross talk issues) I had to figure out a quick solution. I was still a bit limited by the size of my son's pack but in hind sight switching to the mega in the pack would have been such a better plan. The main problem you will have is the sheer number of wires running from the pack to the wand if you go with the mega. If I were doing that I would stick the mega in the wand if there is enough space as fewer wires would go to the pack then. Still the length is going to be a problem with communication and cross talk as these are low voltage devices. It was one of the things that kept me doing a breakout board in the wand.

I'll need to look but I saw a new breakout board on adafruit I think for doing single arduino pin to many non-controlled led's not too long ago. I'll post back here when I find it but it looked like a really good option

dougbevan, 2021-12-20:
If I didn't have the lever-pop mechanism going into the wand it might be possible to get a Mega in there.  Unfortunately, getting a bit tight between switch wiring and the lever-pop mechanicals.

Was that this board you're thinking of?

https://www.adafruit.com/product/1427

With the Mega in the pack, if I were controlling the bar graph with it, I'd need to run 3 ethernet cables from the pack to the wand.  Possible, but starting to get tight I think.

What were the main issues. you had with crosstalk on long cable runs?  Perhaps this is something I can anticipate and get ahead of....

CountDeMonet, 2021-12-21:
Yeah that is the board I was thinking about as it's 5v and can run off the same source as the arduino. It would be the same 3 wires needing to go to the sx1509 as well if you were to go that way. It's just a newer design and 5v which makes things easier.

The biggest issue I had was controlling the audio fx board from the arduino in the wand. Debugging the cross talk was causing gibberish on the arduino side when trying to read the fx board. Never had any issues with the led stuff but running the control arduino in the wand was a no go. I tried all kinds of different wires to see if I could find shielding that would make it work. Nope. Then I ran out of time and just made the decision to put the arduino in the pack and be done with it.

dougbevan, 2021-12-21:
I'm going to order the board and give it a try.  I also see that there are some bare chips that could be useful in minimizing circuit size, like the TLC5917 LED driver.  Might try both and see where I end up.  I'll post back here if useful.

Any time I've used long wires in Arduino projects I end up either needing to debounce in code, else I get errant information at the other end.   I've never been able to solve it electrically although I'm sure there are some things that could be done there as well (I just do not know them yet :)

I think I'll still switch from the Nano to the Mega for the pack, though I likely won't drive the whole bar graph from this alone, instead opting for the SX1509 or one of the above solutions if they prove capable.  The Mega will just leave more options in the future for other modes, and there is plenty of room for it.

Appreciate all your discussion -- it's extremely useful.  Cheers.

CountDeMonet, 2021-12-21:
yeah, debouncing works for standard pin communication but in the case of the audio board and the sx-1509 we're talking about serial communication. It was literally coming in as gobldegook and I was able to find the length at which I got valid data but it was no where near as long as it needed to be. I started to think about switching to wireless communication or bluetooth between the boards in the wand and pack but then I would have needed separate power sources for the pack and wand.

In the end what we came up with works and there are numerous people that have done the bar graph in the wand and I don't believe they have had comms issues with the sx1509 at that distance. Maybe the lower voltage helps there? dunno. Could have also been issues with the arduino I was using as they are knock offs. There is a lot more capability and power in the mega so a lot of the issues I had may be a non issue for you.

dougbevan, 2021-12-21:
Ah, I see, your issues were between the Arduino and Adafruit FX board.  I'm not sure how to go about solving those, I wonder  if there is electronically a cleaner way, I do not know.  It would be an interesting rabbit whole to test.

A wireless solution would be fun to implement.  I suppose you could run a 12V rail down to the thrower to power the wireless device and step it down with a buck converter as needed.

The SX1509 is a solid solution and it works.  I'm intrigued by some of the LED driver chips which might make for a nice package if I do a small custom PCB for the bar graph itself.

CountDeMonet, 2022-02-09:
That's awesome, your kids will be stoked. I know mine still wants to play with it all the time and he's 11 now.

I'm sure there are lots of possible substitutions out there for components. If you come up with code that works using the new hardware you can fork this repo and update it with your changes. I can forward people to it for options.

chris-smith20161, 2022-02-09:
Eric, Did you have any joy with the Afterlife code please?You were going to let me have a copy of were you are at please.RegardsChris Sent from Samsung Mobile on O2
-------- Original message --------From: Eric Banker ***@***.***> Date: 09/02/2022  17:49  (GMT+00:00) To: CountDeMonet/ArduinoProtonPack ***@***.***> Cc: Subscribed ***@***.***> Subject: Re: [CountDeMonet/ArduinoProtonPack] Bar graph code / execution  (Issue #25)
That's awesome, your kids will be stoked. I know mine still wants to play with it all the time and he's 11 now.
I'm sure there are lots of possible substitutions out there for components. If you come up with code that works using the new hardware you can fork this repo and update it with your changes. I can forward people to it for options.

—Reply to this email directly, view it on GitHub, or unsubscribe.Triage notifications on the go with GitHub Mobile for iOS or Android.
You are receiving this because you are subscribed to this thread.Message ID: ***@***.***>

CountDeMonet, 2022-02-09:
Chris, that wasn't me who had modified the code for the afterlife cyclotron. I forget who it was but the post was in response to you in the thread

chris-smith20161, 2022-02-10:
Ok thank you. I will try the old thread many thanksSent from Samsung Mobile on O2
-------- Original message --------From: Eric Banker ***@***.***> Date: 09/02/2022  22:39  (GMT+00:00) To: CountDeMonet/ArduinoProtonPack ***@***.***> Cc: chris-smith20161 ***@***.***>, Comment ***@***.***> Subject: Re: [CountDeMonet/ArduinoProtonPack] Bar graph code / execution  (Issue #25)
Chris, that wasn't me who had modified the code for the afterlife cyclotron. I forget who it was but the post was in response to you in the thread

—Reply to this email directly, view it on GitHub, or unsubscribe.Triage notifications on the go with GitHub Mobile for iOS or Android.
You are receiving this because you commented.Message ID: ***@***.***>

sbarabe, 2022-02-10:
> That's awesome, your kids will be stoked. I know mine still wants to play with it all the time and he's 11 now.
>
> I'm sure there are lots of possible substitutions out there for components. If you come up with code that works using the new hardware you can fork this repo and update it with your changes. I can add it as an available fork with different hardware components for others to look at from the main description page

@CountDeMonet  I'll try to do that, I'm noob to Github and can't quite grasp the architecture yet.

It's hard to fit STL to my requirements, by any chance, no pushing, are your models pieces available in STEP or Fusion 360 ? No pushing, just asking...

CountDeMonet, 2022-02-10:
The files I used were modified from existing stl's and custom made files I did using 3d Builder. Some I have 3mf files for but most only in stl.

sbarabe, 2022-02-10:
Ok you are really patient because trying to modify stl with precision is a pain in the ass! I think that I'm gonna redo the main gunbox in Fusion 360 to fit my hardware...

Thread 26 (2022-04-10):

Use of another soundboard

DTMC78, 2022-04-10:
First of all … thank you for your awesome work!

As the Adafruit sound Fx is running into some limitations (only 16mb) would it be possible to switch to another soundboard without changing too much code?

https://www.adafruit.com/product/3436

I am not really into coding, so any help would be greatly appreciated.

Dirk

CountDeMonet, 2022-04-10:
Most of the sound clips are quite small. I actually use the same board with my droid which has a lot more audio than this one. That project has about 100 audio clips and music on it you just have to be careful with how you encode the audio.

That said, sure you could try another audio board. Make sure it is something that has an interface that the arduino can control and then you would need to modify the initialize and playback functions. Maybe have to change the way the audio is triggered but it's doable.

DTMC78, 2022-04-14:
Thanks for your reply!

Bought some SoundFX now, only issue I have is that its not recognized as an usb drive :(

And as I didnt look closely, I did not buy an [Adafruit](https://www.adafruit.com/product/2220) but instead ordered an https://www.adafruit.com/product/2341 which is the MINI version.
Any chance I will get it to work?

acfq48, 2022-10-11:
If you don't know how to code and don't want to switch sound boards, you
can instead do what I did and redo the audio at a lower quality.  The
sounds won't sound cd quality but you can fit more into the 16mb.  The
benefit of the sound board over other SD card options is in latency.  The
board trigger sounds almost instantaneously.  Some SD card players don't.

You can use audacity on PC to downstate the audio for free.  It's just a
little time consuming.  Just make sure that the audio files are the same
type as the ones that the adafruit board can accept.

Hope that helps.

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

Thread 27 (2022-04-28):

Slow bar graph

jack-626, 2022-04-28:
Hi,

I have hooked up my bar graph on a breadboard to test it and its very slow. if i move around the sparkfun board or the breadboard it can stop completely or speed up to the normal speed. im not sure why this could be happening?

heres a video of it happening: https://www.youtube.com/watch?v=_VRVlzpF2B4
im still waiting for the 5 led bar graph to be delivered which is why im using 2x 10 led ones
and i couldn't find any resistor arrays in stock so im using normal 330 ohm resistors.
could these changes cause the issues?

Thanks!

CountDeMonet, 2022-04-28:
do you have the soundboard hooked up?

jack-626, 2022-04-28:
Thanks for the quick reply!
I just tried it with the soundboard plugged in and its running at the right speed now!
Thank you for the help!

Closed 2022-04-28.

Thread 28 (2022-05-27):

Only a knocking sound when starting

Oburi1985, 2022-05-27:
Hi, I have a problem with the soundboard. I got only a fast "knocking" sound when I start the pack. I already checked all the wiring, but nothing helped. Anyone had the same issue before?
Thanks guys!

CountDeMonet, 2022-05-27:
The sound board is one of the things that can be tested outside of the full software using a tutorial from adafruit. I always recommend people test the audio board following the instructions as it's really straight forward and you can interactively mess with the board. Here is the documentation

https://learn.adafruit.com/adafruit-audio-fx-sound-board/serial-audio-control

When debugging wiring have a simpler setup to work with is a huge help.

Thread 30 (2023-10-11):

Powercell not working properly

ghostbuster84, 2023-10-11:
While powered on, the powercell boots up with multiple different colors on the LEDs, and only turns on 12 lights. 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

Here is a picture for reference when fully on. Is this normal for the spirit code, or is something wrong with my LEDs?

acfq48, 2023-10-13:
That doesn't look right to me.  It should all be blue on the power cell
lights.  It does look like the animation sequence is correct.  Make sure
that you have true RGB neopixels and not just a strip with only certain
colored pixels.

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

ghostbuster84, 2023-10-13:
So, does the animation only do 12 of the 16 lights? Also, the sticks say they are rgbw, so I'd think it should be working. I guess I might have to order another set to make sure.

CountDeMonet, 2023-10-13:
There are different multi led sticks that are triggered differently. I've run into this once before. Do you have a link to the sticks you purchased? The detail you are looking for in the specs for the sticks are "WS2812 5050 RGB LED"

You can increase the number of led's used in the animation. On my spirit pack I could only fit 12 of the led's in the available area so I made it configurable. Look for the line that says

const int powercellLedCount = 14;   // total number of led's in the animation

ghostbuster84, 2023-10-13:
This is the one i bought the first time: Adafruit Industries NeoPixel... https://www.amazon.com/dp/B08Y65TQXL?ref=ppx_pop_mob_ap_share

ghostbuster84, 2023-10-13:
I just bought another set, but using the link you have in the Readme file. I guess I didn't do that for that last one.

CountDeMonet, 2023-10-13:
this is the correct one for future reference.

https://www.amazon.com/Adafruit-NeoPixel-Arduino-Integrated-Drivers/dp/B00IEDH26K/?

you can probably get those cool white ones to work but you would need to play with the code to get the correct colors. I've never worked with the cool white ones before and it appears they are either setup differently or the colors are set differently.

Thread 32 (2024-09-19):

Animation is very slow

NvdGoorbergh, 2024-09-19:
Hi, I am trying to make a 3d printed proton pack and came across your github page. I had an arduino laying around with some jewels and bars and thought to give it a try. When I loaded the code onto my Uno or Nano the animation was playing correctly but was very slow. So slow that the startup animation took almost 2 minutes to finish.

It also seems to skip a beat after a few steps.
Is that something you also recognize? It happens on both micro controllers.

CountDeMonet, 2024-09-19:
which code are you using?

I have seen slowness if the audio board is not connected or not setup correctly.

NvdGoorbergh, 2024-09-19:
That is a good one. I was planning on adding sound later so I used the non spirit code.
will check out the other code and see if that works. (After receiving new parts, accidentally burned trough my led bar 😅)

thanks! Will let you know if that solved it :).

CountDeMonet, 2024-09-20:
You can comment out the code that calls the audio board. The slowdown is
caused by something in the library for the board.

The spirit code is wired slightly differently from the full pack because I
wanted to make it easy to setup. Just be aware of that

On Thu, Sep 19, 2024 at 4:50 PM NvdGoorbergh ***@***.***>
wrote:

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

NvdGoorbergh, 2024-09-21:
Thanks! Will chexk it out when the replacement parts arrive. How many wires are going trough the loom to the wand? I would like to have the quickconnect but need to know how many pins are needed 😅

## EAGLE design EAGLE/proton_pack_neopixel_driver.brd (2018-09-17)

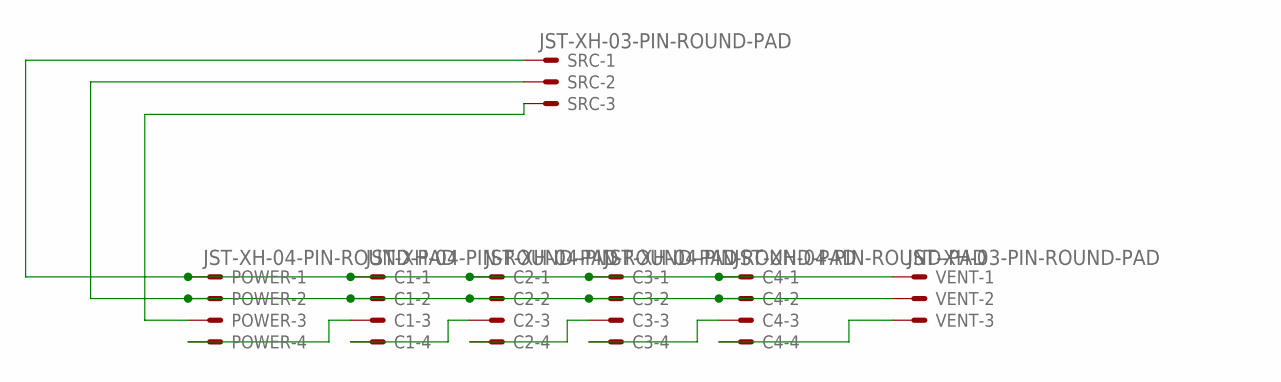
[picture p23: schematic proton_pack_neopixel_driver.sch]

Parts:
C1, C2, C3, C4: JST-XH-04-PIN-ROUND-PAD; JST-XH-04-PACKAGE-ROUND-PAD
POWER: JST-XH-04-PIN-ROUND-PAD; JST-XH-04-PACKAGE-ROUND-PAD
SRC: JST-XH-03-PIN-ROUND-PAD; JST-XH-03-PACKAGE-ROUND-PAD
VENT: JST-XH-03-PIN-ROUND-PAD; JST-XH-03-PACKAGE-ROUND-PAD

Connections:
unnamed: C1.3, POWER.4
unnamed: C1.4, C2.3
unnamed: C2.4, C3.3
unnamed: C3.4, C4.3
unnamed: C4.4, VENT.3
unnamed: C1.2, C2.2, C3.2, C4.2, POWER.2, SRC.2, VENT.2
unnamed: C1.1, C2.1, C3.1, C4.1, POWER.1, SRC.1, VENT.1
unnamed: POWER.3, SRC.3

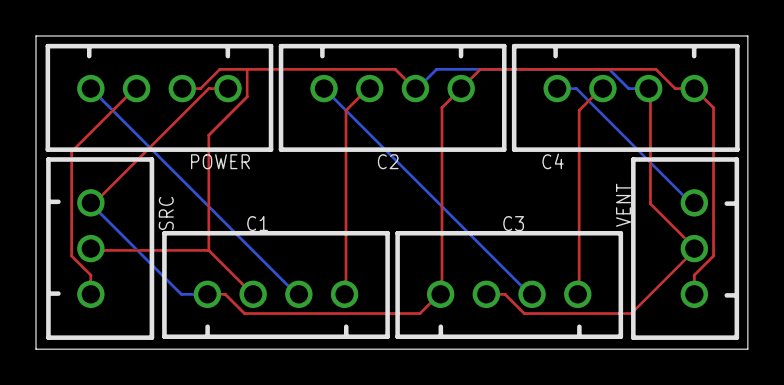
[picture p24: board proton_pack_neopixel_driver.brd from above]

Board: 2 copper layers, 39.5 x 17.4 mm, 7 parts (0 on the bottom side), 8 nets.

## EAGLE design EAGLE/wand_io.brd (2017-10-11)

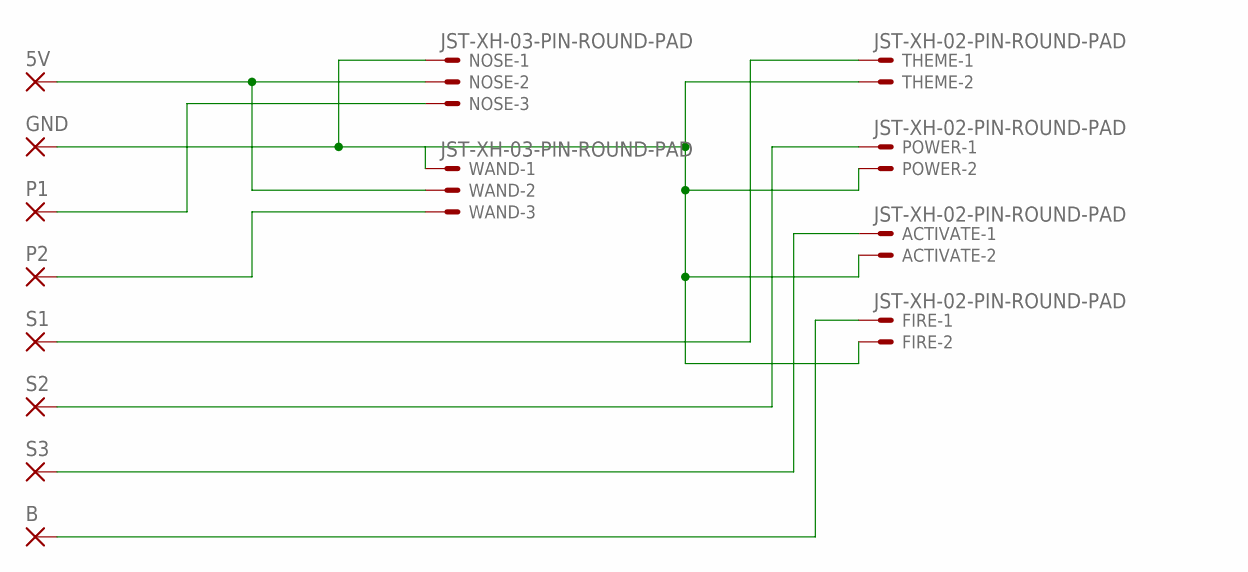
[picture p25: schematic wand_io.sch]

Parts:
5V: 2,54/1,1
ACTIVATE: JST-XH-02-PIN-ROUND-PAD; JST-XH-02-PACKAGE-ROUND-PAD
B: 2,54/1,1
FIRE: JST-XH-02-PIN-ROUND-PAD; JST-XH-02-PACKAGE-ROUND-PAD
GND: 2,54/1,1
NOSE: JST-XH-03-PIN-ROUND-PAD; JST-XH-03-PACKAGE-ROUND-PAD
P1, P2: 2,54/1,1
POWER: JST-XH-02-PIN-ROUND-PAD; JST-XH-02-PACKAGE-ROUND-PAD
S1, S2, S3: 2,54/1,1
THEME: JST-XH-02-PIN-ROUND-PAD; JST-XH-02-PACKAGE-ROUND-PAD
WAND: JST-XH-03-PIN-ROUND-PAD; JST-XH-03-PACKAGE-ROUND-PAD

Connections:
unnamed: ACTIVATE.2, FIRE.2, GND.1, NOSE.1, POWER.2, THEME.2, WAND.1
unnamed: 5V.1, NOSE.2, WAND.2
unnamed: B.1, FIRE.1
unnamed: NOSE.3, P1.1
unnamed: P2.1, WAND.3
unnamed: S1.1, THEME.1
unnamed: POWER.1, S2.1
unnamed: ACTIVATE.1, S3.1

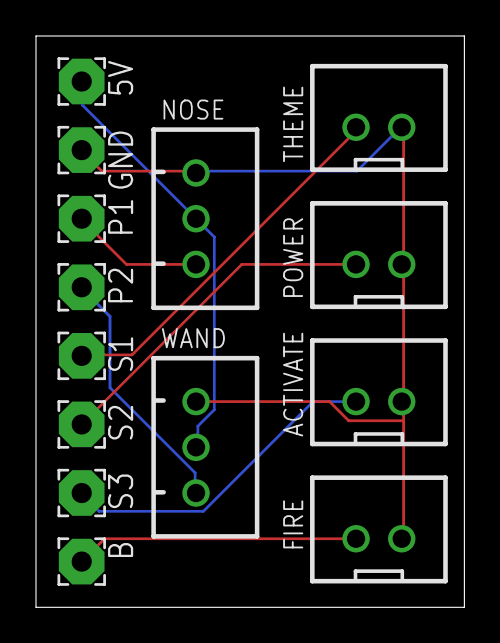
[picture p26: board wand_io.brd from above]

Board: 2 copper layers, 23.8 x 31.7 mm, 14 parts (0 on the bottom side), 8 nets.

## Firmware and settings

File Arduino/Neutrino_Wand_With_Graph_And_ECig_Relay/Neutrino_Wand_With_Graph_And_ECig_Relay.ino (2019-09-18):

#include <QueueArray.h>

#include <Wire.h> // Include the I2C library (required)
#include <SparkFunSX1509.h> // Include SX1509 library

// for the sound board
#include <SoftwareSerial.h>
#include "Adafruit_Soundboard.h"

#include <Adafruit_NeoPixel.h>

// for led triggers
#define HIGH 0x1
#define LOW  0x0

// SX1509 I2C address (set by ADDR1 and ADDR0 (00 by default):
const byte SX1509_ADDRESS = 0x3E;  // SX1509 I2C address
SX1509 io; // Create an SX1509 object to be used throughout

// bargraph helper variables
int seq_1_current = 0;  // current led in sequence 1
const int num_led = 15; // total number of leds in bar graph

// SX1509 pin definitions for the leds on the graph:
const byte SX1509_BAR_01 = 0;
const byte SX1509_BAR_02 = 1;
const byte SX1509_BAR_03 = 2;
const byte SX1509_BAR_04 = 3;
const byte SX1509_BAR_05 = 4;
const byte SX1509_BAR_06 = 5;
const byte SX1509_BAR_07 = 6;
const byte SX1509_BAR_08 = 7;
const byte SX1509_BAR_09 = 8;
const byte SX1509_BAR_10 = 9;
const byte SX1509_BAR_11 = 10;
const byte SX1509_BAR_12 = 11;
const byte SX1509_BAR_13 = 12;
const byte SX1509_BAR_14 = 13;
const byte SX1509_BAR_15 = 14;

// Relay Pin for ECig
int relayPin = 13;

// neopixel pins / setup
#define NEO_POWER 2 // for cyclotron and powercell
Adafruit_NeoPixel powerStick = Adafruit_NeoPixel(48, NEO_POWER, NEO_GRB + NEO_KHZ800);

#define NEO_NOSE 3 // for nose of wand
Adafruit_NeoPixel noseJewel = Adafruit_NeoPixel(7, NEO_NOSE, NEO_GRB + NEO_KHZ800);

#define NEO_WAND 4 // for nose of wand
Adafruit_NeoPixel wandLights = Adafruit_NeoPixel(4, NEO_WAND, NEO_GRB + NEO_KHZ800);

// LED indexes into the neopixel powerstick chain for the cyclotron. Each stick has 8 neopixels for a total of
// 16 with an index starting at 0. These offsets are because my powercell window only shows 13 leds. If you can show more
// change the offset index and powercell count to get more or less lit.
const int powercellLedCount = 14;                                         // total number of led's in the animation
const int powercellIndexOffset = 1;                                       // first led offset into the led chain for the animation

// These are the indexes for the led's on the chain. Each jewel has 7 LEDs. If you are using a single neopixel or
// some other neopixel configuration you will need to update these indexes to match where things are in the chain
int c1Start = 16;
int c1End = 22;
int c2Start = 23;
int c2End = 29;
int c3Start = 30;
int c3End = 36;
int c4Start = 37;
int c4End = 43;
int ventStart = 44;
int ventEnd = 47;

// inputs for switches and buttons
const int THEME_SWITCH = 5;
const int STARTUP_SWITCH = 6;
const int SAFETY_SWITCH = 7;
const int FIRE_BUTTON = 8;

// soundboard pins and setup
#define SFX_RST 9
#define SFX_RX 10
#define SFX_TX 11
const int ACT = 12;    // this allows us to know if the audio is playing

SoftwareSerial ss = SoftwareSerial(SFX_TX, SFX_RX);
Adafruit_Soundboard sfx = Adafruit_Soundboard( &ss, NULL, SFX_RST);

// ##############################
// available options
// ##############################
const bool useGameCyclotronEffect = true;   // set this to true to get the fading previous cyclotron light in the idle sequence
const bool useCyclotronFadeInEffect = false; // Instead of the yellow alternate flashing on boot/vent this fades the cyclotron in from off to red
const bool useDialogTracks = true;          // set to true if you want the dialog tracks to play after firing for 5 seconds

// Possible Pack states
bool powerBooted = false;   // has the pack booted up
bool isFiring = false;      // keeps track of the firing state
bool shouldWarn = false;    // track the warning state for alert audio
bool shuttingDown = false;  // is the pack in the process of shutting down
bool poweredDown = true;    // is the pack powered down
bool venting = false;       // is the pack venting

// physical switch states
bool startup = false;
bool theme = false;
bool safety = false;
bool fire = false;
bool warning = false;

// audio track names on soundboard
char startupTrack[] =   "T00     WAV";
char blastTrack[] =     "T01     WAV";
char endTrack[] =       "T02     WAV";
char idleTrack[] =      "T03     WAV";
char shutdownTrack[] =  "T04     WAV";
char clickTrack[] =     "T05     WAV";
char chargeTrack[] =    "T06     WAV";
char warnTrack[] =      "T07     WAV";
char ventTrack[] =      "T08     WAV";
char texTrack[] =       "T09     WAV";
char choreTrack[] =     "T10     WAV";
char toolsTrack[] =     "T11     WAV";
char listenTrack[] =    "T12     WAV";
char thatTrack[] =      "T13     WAV";
char neutronizedTrack[] = "T14     WAV";
char boxTrack[] =       "T15     WAV";
char themeTrack[] =     "T16     OGG";

// this queue holds a shuffled list of dialog tracks we can pull from so we don't
// play the same ones twice
QueueArray <int> dialogQueue;
int numDialog = 7;

// timer trigger times/states
unsigned long firingStateMillis;
const unsigned long firingWarmWaitTime = 5000;  // how long to hold down fire for lights to speed up
const unsigned long firingWarnWaitTime = 10000;  // how long to hold down fire before warning sounds

// Arduino setup function
void setup() {
  // softwareserial at 9600 baud for the audio board
  ss.begin(9600);

  // set act modes for the fx board
  pinMode(ACT, INPUT);

  // Depending on your relay this may need to be updated.
  pinMode(relayPin, OUTPUT);
  // If relay defaults to on set the pin HIGH on init
  digitalWrite(relayPin, LOW);

  // configure nose jewel
  noseJewel.begin();
  noseJewel.setBrightness(100);
  noseJewel.show(); // Initialize all pixels to 'off'

  // configure powercell/cyclotron
  powerStick.begin();
  powerStick.setBrightness(75);
  powerStick.show(); // Initialize all pixels to 'off'

  // configure wand lights
  wandLights.begin();
  wandLights.setBrightness(75);
  wandLights.show();

  // set the modes for the switches/buttons
  pinMode(THEME_SWITCH, INPUT);
  digitalWrite(THEME_SWITCH, HIGH);
  pinMode(STARTUP_SWITCH, INPUT);
  digitalWrite(STARTUP_SWITCH, HIGH);
  pinMode(SAFETY_SWITCH, INPUT);
  digitalWrite(SAFETY_SWITCH, HIGH);
  pinMode(FIRE_BUTTON, INPUT);
  digitalWrite(FIRE_BUTTON, HIGH);
  // Call io.begin(<address>) to initialize the SX1509. If it
  // successfully communicates, it'll return 1.
  if (!io.begin(SX1509_ADDRESS)) {
    while (1) ; // If we fail to communicate, loop forever for now but it would be nice to warn the user somehow
  }

  // configuration for the bargraph LED's
  io.pinMode(SX1509_BAR_01, OUTPUT);
  io.pinMode(SX1509_BAR_02, OUTPUT);
  io.pinMode(SX1509_BAR_03, OUTPUT);
  io.pinMode(SX1509_BAR_04, OUTPUT);
  io.pinMode(SX1509_BAR_05, OUTPUT);
  io.pinMode(SX1509_BAR_06, OUTPUT);
  io.pinMode(SX1509_BAR_07, OUTPUT);
  io.pinMode(SX1509_BAR_08, OUTPUT);
  io.pinMode(SX1509_BAR_09, OUTPUT);
  io.pinMode(SX1509_BAR_10, OUTPUT);
  io.pinMode(SX1509_BAR_11, OUTPUT);
  io.pinMode(SX1509_BAR_12, OUTPUT);
  io.pinMode(SX1509_BAR_13, OUTPUT);
  io.pinMode(SX1509_BAR_14, OUTPUT);
  io.pinMode(SX1509_BAR_15, OUTPUT);

  // set everything off initially
  shutdown_leds();
}

/* ************* Audio Board Helper Functions ************* */
// helper function to play a track by name on the audio board
void playAudio( char* trackname, int playing ) {
  // stop track if one is going
  if (playing == 0) {
    sfx.stop();
  }

  // now go play
  if (sfx.playTrack(trackname)) {
    sfx.unpause();
  }
}

void playDialogTrack( int playing ) {
  // if the queue is empty reseed it
  if ( dialogQueue.isEmpty() ) {
    for (int i = 1; i <= numDialog; i++) {
      dialogQueue.enqueue(i);
    }
  }

  switch (dialogQueue.dequeue()) {
    case (1):
      playAudio(texTrack, playing);
      break;
    case (2):
      playAudio(listenTrack, playing);
      break;
    case (3):
      playAudio(choreTrack, playing);
      break;
    case (4):
      playAudio(boxTrack, playing);
      break;
    case (5):
      playAudio(thatTrack, playing);
      break;
    case (6):
      playAudio(neutronizedTrack, playing);
      break;
    case (7):
      playAudio(toolsTrack, playing);
      break;
    default:
      playAudio(endTrack, playing);
      break;
  }
}

/* ************* Main Loop ************* */
int cyclotronRunningFadeOut = 255;  // we reset this variable every time we change the cyclotron index so the fade effect works
int cyclotronRunningFadeIn = 0;     // we reset this to 0 to fade the cyclotron in from nothing

// intervals that can be adjusted in real time to speed up animations
unsigned long pwr_interval = 60;        // interval at which to cycle lights for the powercell. We update this in the loop to speed up the animation so must be declared here (milliseconds)
unsigned long cyc_interval = 1000;      // interval at which to cycle lights for the cyclotron.
unsigned long cyc_fade_interval = 15;   // fade the inactive cyclotron to light to nothing
unsigned long firing_interval = 40;     // interval at which to cycle firing lights on the bargraph. We update this in the loop to speed up the animation so must be declared here (milliseconds).

void loop() {
  // get the current time
  unsigned long currentMillis = millis();

  // find out of the audio board is playing audio
  int playing = digitalRead(ACT);

  // get the current switch states
  int theme_switch = digitalRead(THEME_SWITCH);

  // if the theme switch has recently changed from off to on we
  // should play the full ghostbusters theme song
  if (theme_switch == 1) {
    if (theme == false) {
      playAudio(themeTrack, playing);
      theme = true;
    }
  } else {
    theme = false;
  }

  int startup_switch = digitalRead(STARTUP_SWITCH);
  int safety_switch = digitalRead(SAFETY_SWITCH);
  int fire_button = digitalRead(FIRE_BUTTON);

  // while the startup switch is set on
  if (startup_switch == 1) {
    // in general we always try to play the idle sound if started
    if (playing == 1 && startup == true) {
      playAudio(idleTrack, playing);
    }

    // choose the right powercell animation sequence for booted/on
    if ( powerBooted == true ) {
      // standard idle power sequence for the pack
      poweredDown = false;
      shuttingDown = false;
      venting = false;
      setWandLightState(3, 0, 0); //set sloblow red
      setVentLightState(ventStart, ventEnd, 2);
      powerSequenceOne(currentMillis, pwr_interval, cyc_interval, cyc_fade_interval);
    } else {
      // boot up the pack. powerSequenceBoot will set powerBooted when complete
      powerSequenceBoot(currentMillis);
      setWandLightState(3, 7, currentMillis);   //set sloblow red blinking
    }

    // if we are not started up we should play the startup sound and begin the boot sequence
    if (startup == false) {
      startup = true;
      playAudio(startupTrack, playing);

      // get the current safety switch state
      if (safety_switch == 1 && safety == false) {
        safety = true;
      }
    }

    if ( startup == true && safety_switch == 1 ) {
      if ( venting == false && powerBooted == true ) {
        setWandLightState(1, 2, 0);    //  set back light orange
        setWandLightState(2, 1, 0);    //  set body led white
      } else {
        setWandLightState(1, 4, 0);    //  set back light off
        setWandLightState(2, 4, 0);    //  set body led off
      }

      // if the safety switch is set off then we can fire when the button is pressed
      if ( fire_button == 0) {
        // if the button is just pressed we clear all led's to start the firing animations
        if ( isFiring == false ) {
          shutdown_leds();
          isFiring = true;
        }

        // show the firing bargraph sequence
        barGraphSequenceTwo(currentMillis);

        // strobe the nose pixels
        fireStrobe(currentMillis);

        // now powercell/cyclotron/wand lights
        // if this is the first time reset some variables and play the blast track
        if (fire == false) {
          shouldWarn = false;
          fire = true;
          firingStateMillis = millis();
          playAudio(blastTrack, playing);
        } else {
          // find out what our timing is
          unsigned long diff = (unsigned long)(millis() - firingStateMillis);

          if ( diff > firingWarnWaitTime) { // if we are in the fire warn interval
            pwr_interval = 10;      // speed up the powercell animation
            firing_interval = 20;   // speed up the bar graph animation
            cyc_interval = 50;      // really speed up cyclotron
            cyc_fade_interval = 5;  // speed up the fade of the cyclotron
            if (playing == 1 || shouldWarn == false ) {
              shouldWarn = true;
              playAudio(warnTrack, playing); // play the firing track with the warning
            }
            setWandLightState(0, 8, currentMillis);    // set top light red flashing fast
          } else if ( diff > firingWarmWaitTime) { // if we are in the dialog playing interval
            pwr_interval = 30;      // speed up the powercell animation
            firing_interval = 30;   // speed up the bar graph animation
            cyc_interval = 200;     // speed up cyclotron
            cyc_fade_interval = 10; // speed up the fade of the cyclotron
            if (playing == 1) {
              playAudio(blastTrack, playing); // play the normal blast track
            }
            setWandLightState(0, 6, currentMillis);    // set top light orange flashing
          }
        }
      } else { // if we were firing and are no longer reset the leds
        if ( isFiring == true ) {
          shutdown_leds();
          isFiring = false;
        }

        // and do the standard bargraph sequence
        barGraphSequenceOne(currentMillis);

        if (fire == true) { // if we were firing let's reset the animations and play the correct final firing track
          clearFireStrobe();
          setWandLightState(0, 4, currentMillis);    // set top light off

          pwr_interval = 60;
          firing_interval = 40;
          cyc_interval = 1000;
          cyc_fade_interval = 15;
          fire = false;

          // see if we've been firing long enough to get the dialog or vent sounds
          unsigned long diff = (unsigned long)(millis() - firingStateMillis);

          if ( diff > firingWarnWaitTime) { // if we are past the warning let's vent the pack
            playAudio(ventTrack, playing);
            venting = true;
            clearPowerStrip(); // play the boot animation on the powercell
          } else if ( diff > firingWarmWaitTime) { // if in the dialog time play the dialog in sequence
            if ( useDialogTracks == true ) {
              playDialogTrack(playing);
            } else {
              playAudio(endTrack, playing);
            }
          } else {
            playAudio(endTrack, playing);
          }
        }
      }

      // if the safety was just changed play the click track
      if (safety == false) {
        safety = true;
        playAudio(chargeTrack, playing);
      }
    } else {
      // if the safety is switched off play the click track
      if (safety == true) {
        setWandLightState(1, 4, 0);    // set back light off
        setWandLightState(2, 4, 0);    // set body off
        safety = false;
        playAudio(clickTrack, playing);
      }
    }
  } else { // if we are powering down
    if ( poweredDown == false ) {
      if ( shuttingDown == false ) {
        playAudio(shutdownTrack, playing); // play the pack shutdown track
        shuttingDown = true;
      }
      cyclotronRunningFadeOut = 255;
      powerSequenceShutdown(currentMillis);
    } else {
      if (startup == true) { // if started reset the variables
        clearPowerStrip(); // clear all led's
        shutdown_leds();
        startup = false;
        safety = false;
        fire = false;
      }
    }
  }
  delay(1);
}

/*************** Wand Light Helpers *********************/
unsigned long prevFlashMillis = 0; // last time we changed a powercell light in the idle sequence
bool flashState = false;
const unsigned long wandFastFlashInterval = 100; // interval at which we flash the top led on the wand
const unsigned long wandMediumFlashInterval = 500; // interval at which we flash the top led on the wand

void setWandLightState(int lednum, int state, unsigned long currentMillis) {
  switch ( state ) {
    case 0: // set led red
      wandLights.setPixelColor(lednum, wandLights.Color(255, 0, 0));
      break;
    case 1: // set led white
      wandLights.setPixelColor(lednum, wandLights.Color(255, 255, 255));
      break;
    case 2: // set led orange
      wandLights.setPixelColor(lednum, wandLights.Color(255, 127, 0));
      break;
    case 3: // set led blue
      wandLights.setPixelColor(lednum, wandLights.Color(0, 0, 255));
      break;
    case 4: // set led off
      wandLights.setPixelColor(lednum, 0);
      break;
    case 5: // fast white flashing
      if ((unsigned long)(currentMillis - prevFlashMillis) >= wandFastFlashInterval) {
        prevFlashMillis = currentMillis;
        if ( flashState == false ) {
          wandLights.setPixelColor(lednum, wandLights.Color(255, 255, 255));
          flashState = true;
        } else {
          wandLights.setPixelColor(lednum, 0);
          flashState = false;
        }
      }
      break;
    case 6: // slower orange flashing
      if ((unsigned long)(currentMillis - prevFlashMillis) >= wandMediumFlashInterval) {
        prevFlashMillis = currentMillis;
        if ( flashState == false ) {
          wandLights.setPixelColor(lednum, wandLights.Color(255, 127, 0));
          flashState = true;
        } else {
          wandLights.setPixelColor(lednum, 0);
          flashState = false;
        }
      }
      break;
    case 7: // medium red flashing
      if ((unsigned long)(currentMillis - prevFlashMillis) >= wandMediumFlashInterval) {
        prevFlashMillis = currentMillis;
        if ( flashState == false ) {
          wandLights.setPixelColor(lednum, wandLights.Color(255, 0, 0));
          flashState = true;
        } else {
          wandLights.setPixelColor(lednum, 0);
          flashState = false;
        }
      }
      break;
    case 8: // fast red flashing
      if ((unsigned long)(currentMillis - prevFlashMillis) >= wandFastFlashInterval) {
        prevFlashMillis = currentMillis;
        if ( flashState == false ) {
          wandLights.setPixelColor(lednum, wandLights.Color(255, 0, 0));
          flashState = true;
        } else {
          wandLights.setPixelColor(lednum, 0);
          flashState = false;
        }
      }
      break;
  }

  wandLights.show();
}

/*************** Vent Light *************************/
void setVentLightState(int startLed, int endLed, int state ) {
  switch ( state ) {
    case 0: // set all leds to white
      for (int i = startLed; i <= endLed; i++) {
        powerStick.setPixelColor(i, powerStick.Color(255, 255, 255));
      }
      // Set the relay to on while venting. If relay is off set the pin LOW
      digitalWrite (relayPin, HIGH);
      break;
    case 1: // set all leds to blue
      for (int i = startLed; i <= endLed; i++) {
        powerStick.setPixelColor(i, powerStick.Color(0, 0, 255));
      }
      // Set the relay to on while venting. If relay is off set the pin LOW
      digitalWrite (relayPin, HIGH);
      break;
    case 2: // set all leds off
      for (int i = startLed; i <= endLed; i++) {
        powerStick.setPixelColor(i, 0);
      }
      // Set the relay to OFF while not venting. If relay is onf set the pin HIGH
      digitalWrite (relayPin, LOW);
      break;
  }
}

/*************** Powercell/Cyclotron Animations *********************/
// timer helpers and intervals for the animations
unsigned long prevPwrBootMillis = 0;    // the last time we changed a powercell light in the boot sequence
const unsigned long pwr_boot_interval = 60;       // interval at which to cycle lights (milliseconds). Adjust this if

unsigned long prevCycBootMillis = 0;    // the last time we changed a cyclotron light in the boot sequence
const unsigned long cyc_boot_interval = 500;      // interval at which to cycle lights (milliseconds).
const unsigned long cyc_boot_alt_interval = 600;      // interval at which to cycle lights (milliseconds).

unsigned long prevShtdMillis = 0;       // last time we changed a light in the idle sequence
const unsigned long pwr_shutdown_interval = 200;  // interval at which to cycle lights (milliseconds).

unsigned long prevPwrMillis = 0;        // last time we changed a powercell light in the idle sequence
unsigned long prevCycMillis = 0;        // last time we changed a cyclotron light in the idle sequence
unsigned long prevFadeCycMillis = 0;    // last time we changed a cyclotron light in the idle sequence

// LED tracking variables
const int powerSeqTotal = powercellLedCount;                              // total number of led's for powercell 0 based
int powerSeqNum = powercellIndexOffset;                                   // current running powercell sequence led
int powerShutdownSeqNum = powercellLedCount - powercellIndexOffset;       // shutdown sequence counts down

// animation level trackers for the boot and shutdown
int currentBootLevel = powercellIndexOffset;                              // current powercell boot level sequence led
int currentLightLevel = powercellLedCount - powercellIndexOffset;         // current powercell boot light sequence led
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

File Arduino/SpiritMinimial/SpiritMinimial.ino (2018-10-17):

#include <Adafruit_NeoPixel.h>

#define NEO_POWER 2 // for powercell
Adafruit_NeoPixel powerStick = Adafruit_NeoPixel(16, NEO_POWER, NEO_GRB + NEO_KHZ800);

#define NEO_CYCLO 3 // for cyclotron
Adafruit_NeoPixel cyclotron = Adafruit_NeoPixel(4, NEO_CYCLO, NEO_GRB + NEO_KHZ800);

// Possible Pack states
bool powerBooted = false;   // has the pack booted up

// ##############################
// available options
// ##############################
const bool useGameCyclotronEffect = true;     // set this to true to get the fading previous cyclotron light in the idle sequence
const bool useCyclotronFadeInEffect = true;   // Instead of the yellow alternate flashing on boot this fades the cyclotron in from off to red

// ##############################
// bootup animation speeds
// ##############################
const unsigned long pwr_boot_interval = 40;       // How fast to do the powercell drop animation on bootup 
const unsigned long cyc_boot_interval = 400;      // If useCyclotronFadeInEffect is false this alternates the cycltron lights yellow 
const unsigned long cyc_boot_alt_interval = 150;  // How fast to fade in the cyclotron lights from black to red on bootup

// ##############################
// idle animation speeds
// ##############################
const unsigned long pwr_interval = 55;            // how fast the powercell cycles: One 14 led cycle per 756 ms
const unsigned long cyc_interval = 770;           // how fast the cycltron cycles from one cell to the next: One full rotation every 3024 ms
const unsigned long cyc_fade_interval = 1;        // if useGameCyclotronEffect is true this is how fast to fade the previous cyclotron to light to nothing

void setup() {
  // configure powercell/cyclotron
  powerStick.begin();
  powerStick.setBrightness(80);
  powerStick.show(); // Initialize all pixels to 'off'

  cyclotron.begin();
  cyclotron.setBrightness(80);
  cyclotron.show(); // Initialize all pixels to 'off'
}

void loop() {
  // get the current time
  unsigned long currentMillis = millis();
  if( powerBooted == false ){
    powerSequenceBoot(currentMillis);
  } else {
    powerSequenceOne(currentMillis, pwr_interval, cyc_interval, cyc_fade_interval);
  }
  delay(1);
}

int cyclotronRunningFadeOut = 255;  // we reset this variable every time we change the cyclotron index so the fade effect works
int cyclotronRunningFadeIn = 0;     // we reset this to 0 to fade the cyclotron in from nothing
void setCyclotronLightState(int startLed, int endLed, int state ){
  switch ( state ) {
    case 0: // set all leds to red
      for(int i=startLed; i <= endLed; i++) {
        cyclotron.setPixelColor(i, powerStick.Color(255, 0, 0));
      }
      break;
    case 1: // set all leds to orange
      for(int i=startLed; i <= endLed; i++) {
        cyclotron.setPixelColor(i, powerStick.Color(255, 106, 0));
      }
      break;
    case 2: // set all leds off
      for(int i=startLed; i <= endLed; i++) {
        cyclotron.setPixelColor(i, 0);
      }
      break;
    case 3: // fade all leds from red
      for(int i=startLed; i <= endLed; i++) {
        if( cyclotronRunningFadeOut >= 0 ){
          cyclotron.setPixelColor(i, 255 * cyclotronRunningFadeOut/255, 0, 0);
          cyclotronRunningFadeOut--;
        }else{
          cyclotron.setPixelColor(i, 0);
        }
      }
      break;
  case 4: // fade all leds to red
      for(int i=startLed; i <= endLed; i++) {
        if( cyclotronRunningFadeIn < 255 ){
          cyclotron.setPixelColor(i, 255 * cyclotronRunningFadeIn/255, 0, 0);
          cyclotronRunningFadeIn++;
        }else{
          cyclotron.setPixelColor(i, cyclotron.Color(255, 0, 0));
        }
      }
      break;
  }
}

/*************** Powercell/Cyclotron Animations *********************/
/* These allow you to use more than one neopixel per cyclotron if you
 * want it brighter. If using only one set start and end to the same
 * number */
int c1Start = 0;
int c1End = 0;
int c2Start = 1;
int c2End = 1;
int c3Start = 2;
int c3End = 2;
int c4Start = 3;
int c4End = 3;

unsigned long prevPwrBootMillis = 0;    // the last time we changed a powercell light in the boot sequence
unsigned long prevCycBootMillis = 0;    // the last time we changed a cyclotron light in the boot sequence
unsigned long prevPwrMillis = 0;        // last time we changed a powercell light in the idle sequence
unsigned long prevCycMillis = 0;        // last time we changed a cyclotron light in the idle sequence
unsigned long prevFadeCycMillis = 0;    // last time we changed a fading cyclotron light in the idle sequence

// LED indexes into the neopixel powerstick chain for the cyclotron
const int powercellLedCount = 14;   // total number of led's in the animation
int powerSeqNum = 0;                // current running powercell sequence leds

// animation level trackers for the boot and shutdown
int currentBootLevel = 0;                          // current powercell boot level sequence led
int currentLightLevel = powercellLedCount;         // current powercell boot light sequence led
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

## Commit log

2017-09-11 Add the model for the proton wand and most of the sounds
    [clippard.stl, front_handle_mount.stl, front_nose_spacer.stl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]
2017-09-11 add the models for the proton pack for printing. Currently exported for a left handed pack
    [base_1.stl, base_2.stl, base_3.stl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]
2017-09-15 new ion arm that prints easier and easier to finish, more accurate syncgen part, and an m4 motherboard mount
    [ion_1.stl, ion_2.stl, ion_3.stl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]
2017-09-15 loom mount for the syncgen connection
    [syncgen_loom_mount.stl]
2017-09-15 added a bottom to the ion mount. This will give more surface area for the glue
    [ion_1.stl]
2017-09-18 moved some pins around for simplicity, new startup/shutdown animations, initial crack at cyclotron animation
    see https://www.youtube.com/watch?v=2o-0Lq8c1x0 for demo of current
    code. This is initial still and has not been optimized
    [Neutrino_Wand.ino]
2017-09-23 added a new properly scaled HGA, an Nfilter with holes open for vent light, and a motherboard standoff for mounting to alice frame or pvc
    [cyclotron_1_closed.stl, cyclotron_1_open.stl, front_mount_barbs.3mf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]
2017-09-24 Added an option to use the ghostbusters game effect for the cyclotron
    For people that own a Spirit Proton Pack I have uploaded a very simple
    version of the code that simply does the powercell and cyclotron lights.
2017-09-25 First crack at the wand lights. Adds blinking top, orange black, red slowblo, and blue body when activated
    [Neutrino_Wand.ino]
2017-09-26 Added the missing models for the front handle and nose section
    [front_handle_adjuster.stl, front_handle_clear_tube_adapter.stl, front_handle_end_piece.stl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]
2017-09-26 include a mount for individual neopixel led's.
    place pixel in mount, glue mount where you want it, and hot glue the led
    in so it can be removed if needed.
    [individual_neopixel_holder.stl]
2017-09-27 Add 2 neopixels to the powercell/cyclotron chain that can be used to show a venting light in the nfilter
2017-09-27 More work on the wand lights, new cyclotron animation option for startup
    SloBlo now blinks when booting/venting, rear light and vent light are
    tied to activate switch, top light flashes yellow after firing 5 seconds
    and fast red after firing for 10 seconds. As pack vents all wand lights
    shut down, sloblo then flashes red. 2 more neopixels added to the
    powercell/cyclotron chain for doing the nfilter venting effect
2017-09-27 Fixed the powercell configuration and added the abiltiy to offset the start led in the sequence.
    My powercell can only fit 14 led's in the window so I had to add the
    offset and fix the total so I can use only the middle 14 led's
    [Neutrino_Wand.ino]
2017-09-28 individual neopixel holder and powerstrip mount for the powercell
    [individual_neopixel_holder.stl, powercell_neopixel_mount.stl]
2017-09-30 add 4 individual neopixel mount for the nfilter
    [nfilter_venting_neopixel_holder.stl]
2017-09-30 Updated circuit diagrams. Added one for a the spirit halloween upgrade
2017-10-01 new battery icon. All lipos in this setup are 11.1v
2017-10-07 Update diagram, printing the tube connectors now. Also new ion rods and ribbon cable mount
    [booster_straight_barb.stl, front_mount_barbs.3mf, front_mount_barbs.stl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]
2017-10-07 more model updates
    [front_green_tube_barbs.stl, ion_arm_90_female.stl]
2017-10-08 remodelled the back panel knob with less detail. For such a small item my printer can't print it well with the detail so simplified
    [gunbox_back_panel_knob.stl]
2017-10-11 Helper boards for simpler connections. Wand switch and button inputs and neopixel light connections
    [proton_pack_neopixel_driver.brd, wand_io.brd]
2017-10-11 update the light board to use the same jst lib as the other one.
    [proton_pack_neopixel_driver.brd]
2017-10-11 move the audio board pins up one for easier soldering, remove a second digital read of the act as it's not needed, update brightness
2017-10-14 now that I've built the minimal spirit circuit here is the updated code and diagram. 5v out on the buck converter
2017-10-14 a few models for helping to mount the cyclotron and powercell lights
    [cyclotron_individual_neopixel.stl, powercell_neopixel_mount.stl]
2017-10-14 updated diagram for one neopixel per cyclotron hole
2017-10-15 model for powercell updated. I had it reversed
    [powercell_neopixel_mount.stl]
2017-10-15 Alternate Spirit Circuit without the buck converter for simpler wiring
2017-10-16 Mount for the gun and a gun track for it.
    [gunbracket_base.stl, gunbracket_female.stl, gunbracket_male.stl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]
2017-10-16 made the gun track 125mm instead of 120 to better fit the gun
    [guntrack_spirit.stl]
2017-10-17 some model updates
    [front_handle_clear_tube_adapter.stl, front_handle_end_piece.stl, front_handle_wing.stl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]
2017-10-19 add in missing connector for the trigger box
    [gunbox_front_panel_side_connector.stl]
2017-10-19 use white light for wand vent light, in normal fire just stop the track. The tail happens if firing a lot.
2017-10-20 updated track names and added a new click and stream shutdown sound for short bursts. I like this better
    [Neutrino_Wand.ino]
2017-10-23 undid the mirroring of the pack. Now it's in the standard orientation.
    [base_1.stl, base_2.stl, base_3.stl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]
2017-11-19 Add boot animations for spirit pack when power is applied. Option short sound for idle
    [SpiritMinimial.ino]
2018-03-01 updated the timer variables to all be unsigned long. Fixes an animation hiccup that could occur
    [SpiritMinimial.ino]
2018-03-01 updated some of the timer variables. Should resolve some random animation issues
    [Neutrino_Wand.ino]
2018-03-06 updated sound board pinout to match the diagram
2018-08-06 add the back brace standoff
    [back_brace_standoff.stl]
2018-08-09 more models for the back brace
    [back_brace_pvc_plug.stl, back_brace_top.stl]
2018-08-14 some more wiring diagram help for using the eagle boards
2018-09-13 trying to sync up the cyclotron and powercell animations so one full powercell for each cyclotron light
2018-09-17 found the schematics for the boards.
    [proton_pack_neopixel_driver.brd, proton_pack_neopixel_driver.sch, wand_io.sch]
2018-09-17 Fritzing Files
    [Spirit_Proton_Pack.fzz, proton_pack_no_bargraph.fzz, proton_pack_with_bargraph.fzz]
2018-10-10 Remove code stop if the audio board is not working.
    [Neutrino_Wand.ino]
2018-10-10 Remove stop if audio board is not working.
    [Neutrino_Wand_With_Graph.ino]
2019-09-18 simplfy the relay code
2021-12-17 pics of the bar graph proto board
